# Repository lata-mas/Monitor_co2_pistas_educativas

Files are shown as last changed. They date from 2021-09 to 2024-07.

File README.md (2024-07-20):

# Monitor de CO2 con sensores NDIR intercambiables para evaluar la ventilación natural

En este repositorio se encuentran los archivos necesarios para replicar el monitor de CO2 desarrollado en el Instituto de Energías Renovables de la UNAM, ubicado en Temixco, Morelos, México.

Los archivos para el PCB se encuentran en el folder **electric_design**. Los archivos KiCAD del esquema del PCB y el diagrama eléctrico se encuentran en el folder **pcb_src**. Los archivos para maquinar o cortar por láser el PCB se encuentran en el folder **pcb_gerber**. El diagrama eléctrico en formato PDF se encuentra en el folder **pcb_pdf**. Las plantillas para producir el PCB por impresión de pantalla en formato JPG se encuentran en el folder **pcb_jpg**. Adicionalmente, renders tridimensionales del PCB con las partes del monitor se encuentran en el folder **pcb_view3D**. Los archivos para producir la carcasa del monitor de CO2 se encuentran en el folder **hardcase_pdf**. Los archivos FreeCAD se encuentran en el folder **cad**, junto con archivos en PDF para calcar en el folder **hardcase_pdf**, y también archivos en formato STL y DXF en el folder **hardcase_printable**.

El programa, código fuente y binario, se encuentran en el folder **software**. En el folder **notebook** se encuentran libretas de Jupyter con los datos de la calibración hecha y la campaña experimental, los datos se encuentran en el folder **dat**.

# Lista de componentes
| Designador  | Componente | Cantidad | Costo (MXN) | Fuente de materiales |
|---|---|---|---|---|
| ESP8266 | NodeMCU V3.0 Lolin | 1 | 159.0 | [Steren](https://www.steren.com.mx/placa-de-desarrollo-nodemcu-esp8266.html) |
| Sensor CO2  | S8LP | 1 | 800.0 | [Digikey](https://www.digikey.com.mx/es/products/detail/senseair/004-0-0053/10416532) |
| Sensor CO2  | SEN0220 | 1 | 1600.0 | [DFROBOT](https://www.dfrobot.com/index.php?route=product/product&product_id=1565) |
| Sensor CO2  | SCD30 | 1 | 1067.0 | [DigiKey](https://www.digikey.com.mx/es/products/detail/sensirion-ag/SCD30/8445334) |
| Pantalla | Pantalla de 4 dígitos | 1 | 112.0 | [Seeed Studio](https://www.seeedstudio.com/Grove-4-Digit-Display.html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) |
| LED | LED RGB | 1 | 4.3 | [Seeed Studio](https://www.seeedstudio.com/5mm-Triple-Output-LED-RGB-Common-cathode-20-PC-p-623.html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) |
| BUZZER | Zumbador activo | 1 | 27.7 | [Seeed Studio](https://www.seeedstudio.com/Grove-Buzzer.html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) |
| microUSB | Adaptador microUSB | 1 | 7.0 | [UElectronics](https://uelectronics.com/producto/adaptador-micro-usb-tipo-b-hembra-a-dip-pcb-5-pines/) |
| Botón | Botón pulsador | 1 | 27.7 | [Newark](https://www.newark.com/philmore/30-10062/product-range/dp/43W7727?st=button) |
| Batería | Banco de energía 2500 mAh | 1 | 200.0 | [Newark](https://www.newark.com/multicomp/mc011332/power-bank-5-2ah-5vdc/dp/94AC6834?st=power%20bank) |
| R1 | Resistencia de 10 kOhm | 1 | 2.5 | [Newark](https://www.newark.com/arcol/mra0207-10k-b-15ppm-ta/res-10k-0-10-250mw-axial/dp/79Y4556?st=resistor%2010kohm) |
| R2 | Resistencia de 220 Ohm | 3 | 2.5 | [Newark](https://www.newark.com/multicomp-pro/mccfr0w4j0221a50/carbon-film-resistor-220-ohm-250mw/dp/58K5029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) |
| Grove | Cable groove | 1 | 2.5 | [Seeed Studio](https://www.seeedstudio.com/Grove-Universal-4-Pin-Buckled-5cm-Cable-5-PCs-Pack.html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) |
| Terminal | Conector vertical de 4 pines GROVE 2mm | 1  | 2.5  | [Digikey](https://www.digikey.com.mx/en/products/detail/seeed-technology-co-ltd/110990030/5482560) |
| Pines | 40 pines hembra | 2 | 6.7 | [Seeed Studio](https://www.seeedstudio.com/2-54mm-pitch-pin-headers-Female-40pin-in-1-line-p-16.html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) |
| Tornillos | Tornillos M3 x 60 mm | 4 | 5.0 | [Amazon](https://www.amazon.com.mx/gp/product/B08XB8S55X/ref=ppx_yo_dt_b_search_asin_title?ie=UTF8&th=1) |
| Tuercas | Tuercas hexagonales M3-0.5 mm | 4 | 1.0 | [Amazon](https://www.amazon.com.mx/gp/product/B07ZFFFRJ5/ref=ppx_yo_dt_b_search_asin_title?ie=UTF8&th=1) |
| Popote | Popote rígido de plástico | 2 | 3.4 | [Amazon](https://www.amazon.com.mx/Pajitas-Repuesto-Pl%C3%A1stico-Reutilizables-Pinceles/dp/B0925H4F6R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) |
| Cable | Cable jumper o 22-26 AWG 6 cm | 2 | 1.8 | [Adafruit](https://www.adafruit.com/product/794) |

# Instrucciones de armado

El proceso de construcción se divide en cinco etapas. La primera etapa describe el ensamblaje del hardware para el monitor de CO2. La segunda etapa detalla la configuración y el procedimiento de carga del firmware para el ESP8266. En la tercera etapa se realiza una prueba de ensamblaje y en la cuarta etapa se lleva a cabo la configuración para la plataforma IoT. La quinta y última etapa implica el ensamblaje de la carcasa y la conexión de la batería USB si es necesario. Es importante destacar que el monitor de CO2 puede construirse y probarse en ausencia de los sensores de CO2, lo que permite adaptarse a posibles demoras en la entrega de componentes en regiones como México.

### Ensamblaje del monitor de CO2

Los siguientes pasos deben llevarse a cabo una vez que el usuario esté listo para construir el monitor de CO2, considerando que se puede probar y configurar aunque no haya un sensor de CO2 en el momento de la construcción, definiendo un sensor ficticio.

1. La PCB es de doble cara y puede producirse mediante serigrafía o mecanizado. Una de las caras tiene impresa la posición de las resistencias, sensores, led, etc., que se llamará cara frontal y el lado sin etiquetar cara trasera. Ambos lados de la PCB se muestran en la Figura 1a) cara frontal y 1b) cara trasera.
2. Soldar dos cables puente (6 cm de largo) al botón pulsador.
3. Soldar los siguientes componentes en la cara frontal. Cuatro resistencias, que están marcadas en la PCB como R1 para la resistencia de 10 $kOhm$ y R2, R3 y R4 son resistencias de 220 $Ohm$. Soldar dos líneas de quince pines hembra para el ESP8266. Soldar un conector hembra de cuatro pines para el LED. Para el botón, introducir los cables del botón en esta cara, por lo que la soldadura debería estar en la cara trasera. Insertar el conector vertical grove y soldar. En este punto, la PCB debería parecerse a la Figura 1c).
4. En la cara trasera, soldar lo siguiente: Soldar el adaptador MicroUSB y el conector hembra de tres pines para el zumbador, el conector hembra para este último debe estar doblado.
5. Si se usa S8LP, soldar dos líneas de conector hembra de seis pines en la cara trasera. En este punto, la cara trasera de la PCB debería parecerse a la Figura 1d). Luego soldar dos líneas de seis pines al sensor CO2 S8LP y enchufarlo en la PCB como se muestra en la Figura 2a).
6. Si se usa SCD30 o SEN0220, soldar una línea de conector hembra de cuatro pines en la cara trasera y, dependiendo del sensor, conectar como se muestra en la Figura 2b) para SCD30 y como se muestra en la Figura 2c) para SEN0220.
7. Enchufar el cable rojo del LED RGB apuntando al borde de la PCB en la cara frontal.
8. Enchufar la pantalla de 4 dígitos con un cable universal de cuatro pines con hebilla.
9. Enchufar el zumbador en el conector hembra de tres pines doblado.
10. Enchufar el ESP8266 con conexión microUSB alineada con el borde de la PCB.
<table>
  <tr>
    <td>
      <figure>
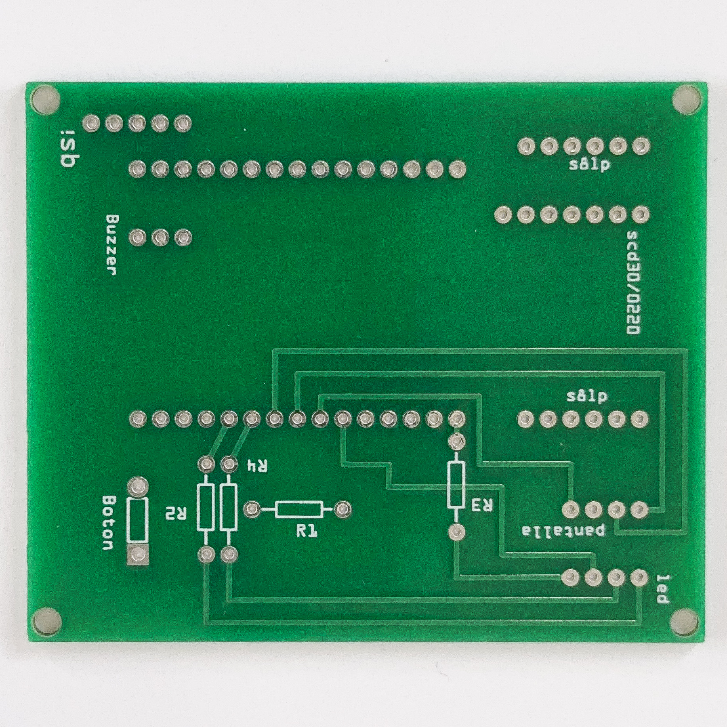
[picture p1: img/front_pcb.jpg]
Cara frontal de la PCB del monitor de CO2 sin componentes a) Cara frontal de la PCB sin componentes
        
        <figcaption>a)</figcaption>
      </figure>
    </td>
    <td>
      <figure>
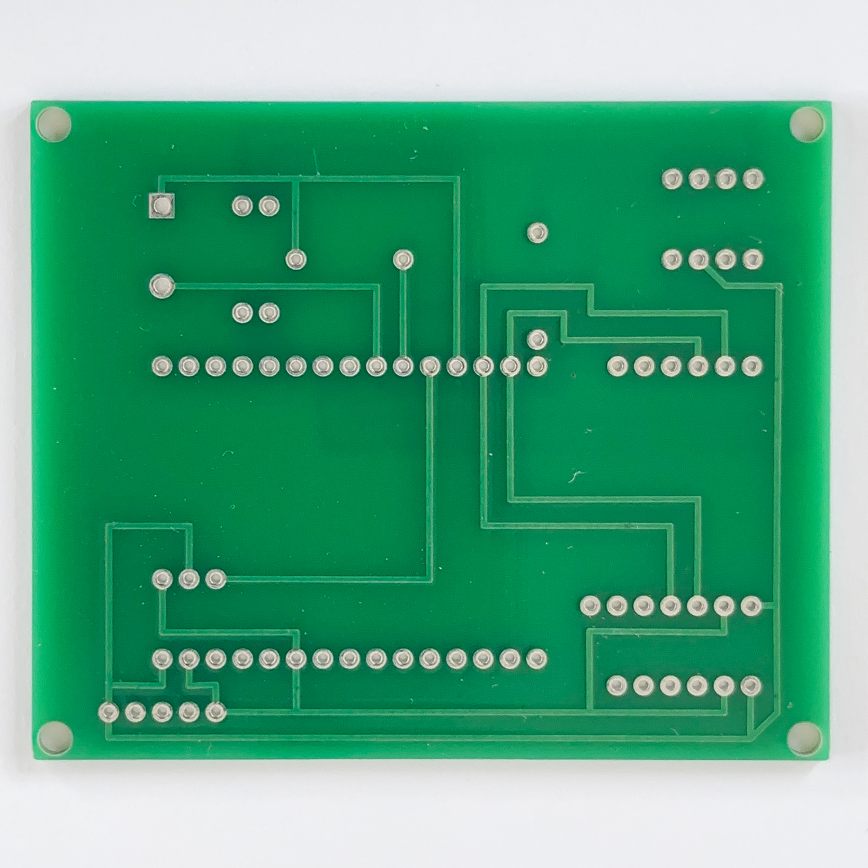
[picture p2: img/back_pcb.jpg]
Cara trasera de la PCB del monitor de CO2 sin componentes b) Cara trasera de la PCB sin componentes
        
        <figcaption>b) </figcaption>
      </figure>
    </td>
  </tr>
  <tr>
    <td>
      <figure>
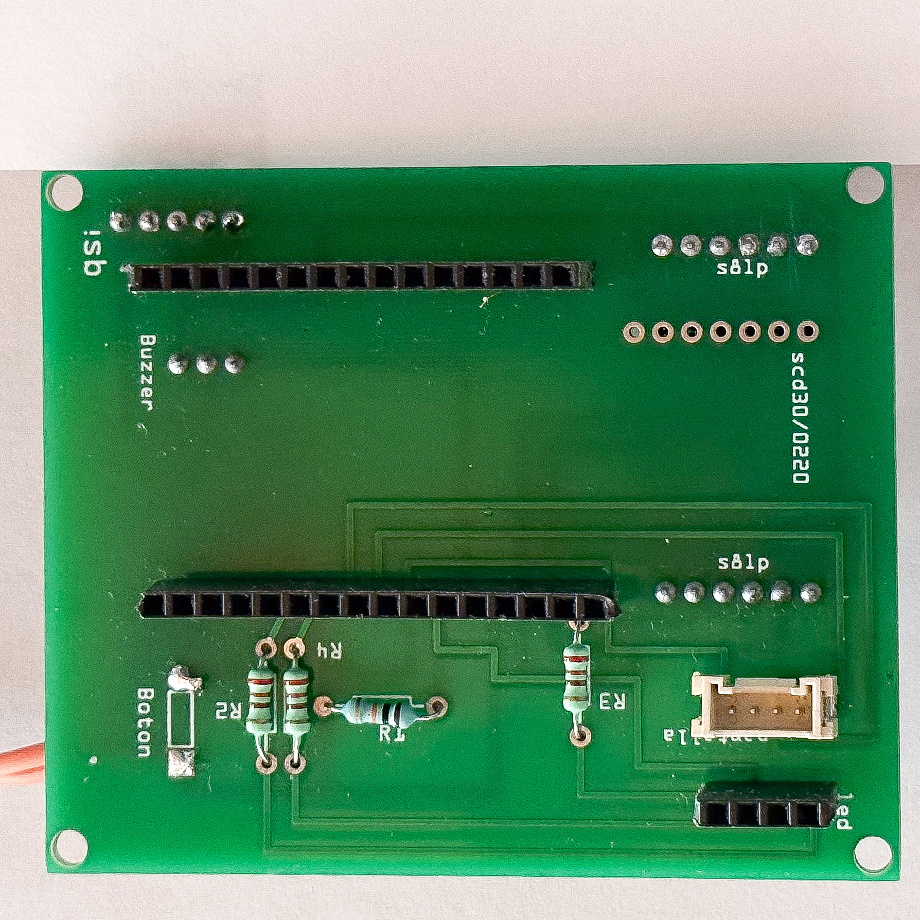
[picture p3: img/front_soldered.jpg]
Cara frontal de la PCB del monitor de CO2 con componentes soldados c) Cara frontal de la PCB con componentes soldados
        
        <figcaption>c) </figcaption>
      </figure>
    </td>
    <td>
      <figure>
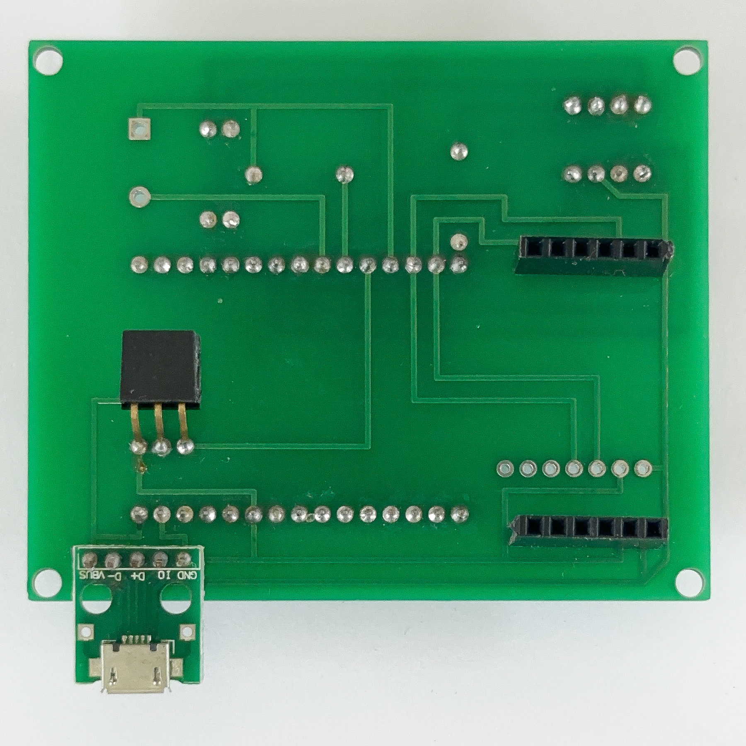
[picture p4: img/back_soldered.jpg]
Cara trasera de la PCB del monitor de CO2 con componentes soldados d) Cara trasera de la PCB con componentes soldados
        
        <figcaption>d) </figcaption>
      </figure>
    </td>
  </tr>
</table>

**Figura 1**: a) Cara frontal y b) cara trasera de la PCB para el monitor de CO2 sin componentes. Tras soldar los componentes c) cara frontal y d) cara trasera de la PCB. La cara frontal tiene etiquetas para los componentes.

<table>
  <tr>
    <td style="text-align: center;">
      <figure>
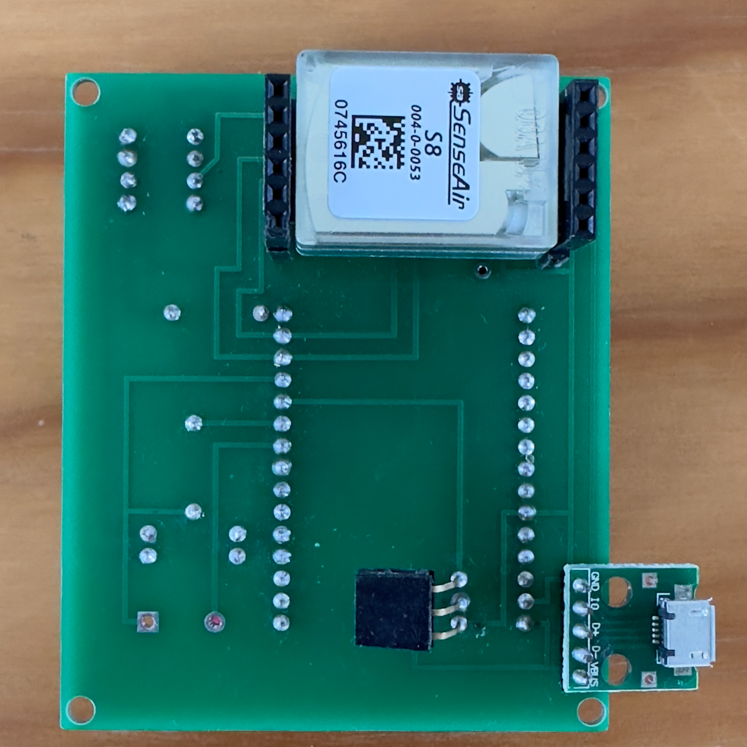
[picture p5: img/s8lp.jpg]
Sensor S8LP a) S8LP
        
        <figcaption>a) S8LP</figcaption>
      </figure>
    </td>
    <td style="text-align: center;">
      <figure>
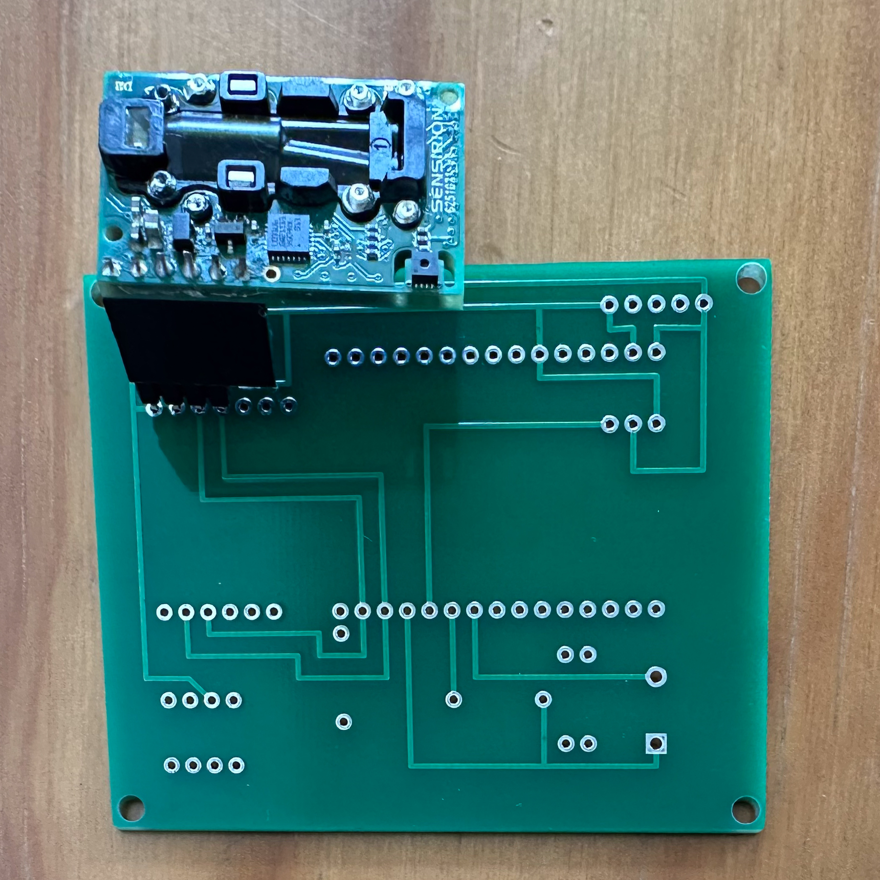
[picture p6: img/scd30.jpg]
Sensor SCD30 b) SCD30
        
        <figcaption>b) SCD30</figcaption>
      </figure>
    </td>
    <td style="text-align: center;">
      <figure>
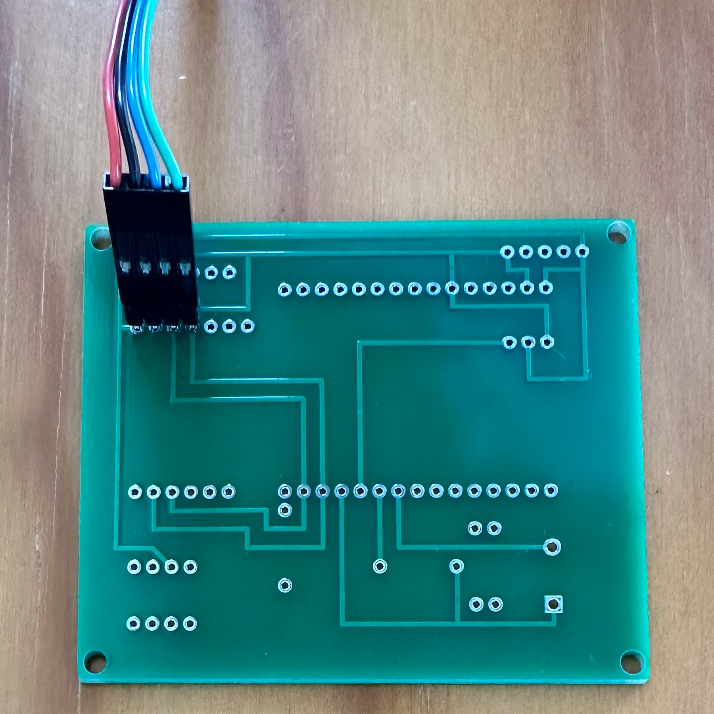
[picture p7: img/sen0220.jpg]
Sensor SEN0220 c) SEN0220
        
        <figcaption>c) SEN0220</figcaption>
      </figure>
    </td>
  </tr>
</table>

<figcaption>**Figura 2**: a) S8LP, b) SCD30, y c) SEN0220 sensores conectados en la cara trasera.</figcaption>

### Configuración y carga del firmware en el ESP8266

Antes de cargar el firmware en el ESP8266, en el archivo .ino, localiza la línea `#define S8LP` y reemplaza `S8LP` con el sensor de CO2 que hayas elegido. Las opciones disponibles son `DUMMY, SEN0220` y `SCD30`. Vale la pena mencionar que la opción `DUMMY` se utiliza cuando el sensor seleccionado no está disponible. Esta opción genera datos simulados, permitiendo evaluaciones preliminares del hardware.

Adicionalmente, en las líneas donde se define:

```
#define CO2_MIN 400
#define CO2_MID 600
#define CO2_MAX 700
```

tienes la opción de configurar los colores verde, amarillo y rojo, respectivamente, que también corresponden a la alarma audible.

En el archivo `arduino_secrets.h`, los usuarios deben especificar la URL de la plataforma IoT ThingsBoard. Además, el ESP8266 establece un servicio web específico para configurar la red WiFi a la que se unirá y el token del dispositivo donde el monitor de CO2 publicará sus datos. El nombre de usuario y contraseña del administrador pueden ajustarse en este archivo o mantenerse como están.

Una vez que todos los cambios necesarios estén hechos, el archivo .ino puede cargarse en el ESP8266 usando el Arduino IDE. Cuando se configura un gran conjunto de monitores de CO2, se recomienda exportar el archivo como un archivo binario. Para hacer esto, una vez abierto el archivo .ino y compilado para verificar errores, el usuario debe ir a Sketch, Export compiled binary y el archivo binario puede cargarse en diferentes monitores de CO2. En la carpeta /software/build del repositorio se puede encontrar el archivo binario que usamos para configurar los monitores de CO2 y un script bash, `foo.sh`, como referencia para cargar el binario usando esptool.

### Prueba de ensamblaje

Al encender el Monitor de CO2, este verificará si el zumbador y el LED RGB están funcionando correctamente. Si ambos funcionan bien, el zumbador emitirá un sonido y el LED RGB mostrará los colores rojo, verde y azul antes de comenzar a funcionar.

### Configuración para la plataforma IoT

Una vez cargado el firmware en el ESP8266 y encendido por primera vez, el monitor de CO2 establece automáticamente un punto de acceso denominado `monitorCO2-XXXXXXXXX` donde las `X` se reemplazan con los últimos nueve dígitos de la dirección MAC de cada ESP8266. Para configurar el token necesario y la información de WiFi, haz lo siguiente:

1. Conéctate a la red WiFi del monitor de CO2 llamada `monitorCO2-XXXXXXXXX` desde un computador cercano.
2. Abre un navegador y navega a `http://192.168.4.1`, donde te llevará a una interfaz de configuración.
3. Inicia sesión utilizando las credenciales predeterminadas: nombre de usuario `admin` y contraseña `password`. Estos corresponden a las constantes `SECRET_WWW_USERNAME` y `SECRET_WWW_PASSWORD` en el archivo .ino del firmware. A menos que el código haya sido modificado, estas serán las credenciales predeterminadas.
4. Luego se te solicitará que ingreses los detalles de la red WiFi que el ESP8266 utilizará para conectarse a Internet junto con su contraseña, también se te pedirá el token del dispositivo.
5. Después de proporcionar esta información, el monitor de CO2 almacenará los datos y desactivará su función de punto de acceso.
6. Reinicia el ESP8266.

Si decides no completar esta configuración, el monitor de CO2 seguirá siendo completamente operativo para mediciones pero no enviará datos a la plataforma IoT y el punto de acceso estará disponible hasta que se realice la configuración.

### Carcasa para el monitor de CO2 y batería

La carcasa del Monitor de CO2 consiste en dos láminas rígidas con recortes para la pantalla, el led y para el botón. Se ensambla con cuatro tornillos, tuercas y dos popotes cortados en ocho piezas (2.5 cm cada pieza) que se utilizan como separadores. Antes de ensamblar la carcasa, el monitor de CO2 debe parecerse a lo mostrado en la Figura 3 a) la cara frontal y b) la trasera usando el S8LP. En la Figura 4 a) se muestran las láminas rígidas para la carcasa con los recortes para el sonido, ranuras, pantalla, botón, led y tornillos para el ensamblaje. La pantalla se asegura a una de las láminas rígidas usando 2 tornillos que generalmente se incluyen con la pantalla. En la misma lámina, hay un orificio donde encaja el LED, en caso de usar tableros opacos. También tiene 4 orificios por los cuales pasarán los tornillos. Esta lámina corresponde a la cara frontal de la PCB. La otra lámina de la carcasa tiene un recorte para asegurar el botón y ranuras para asegurar una ventilación adecuada para el sensor de CO2.

Finalmente, el monitor de CO2 ensamblado con láminas transparentes como carcasa y con una batería USB adjunta se muestra en la Figura 4 b).

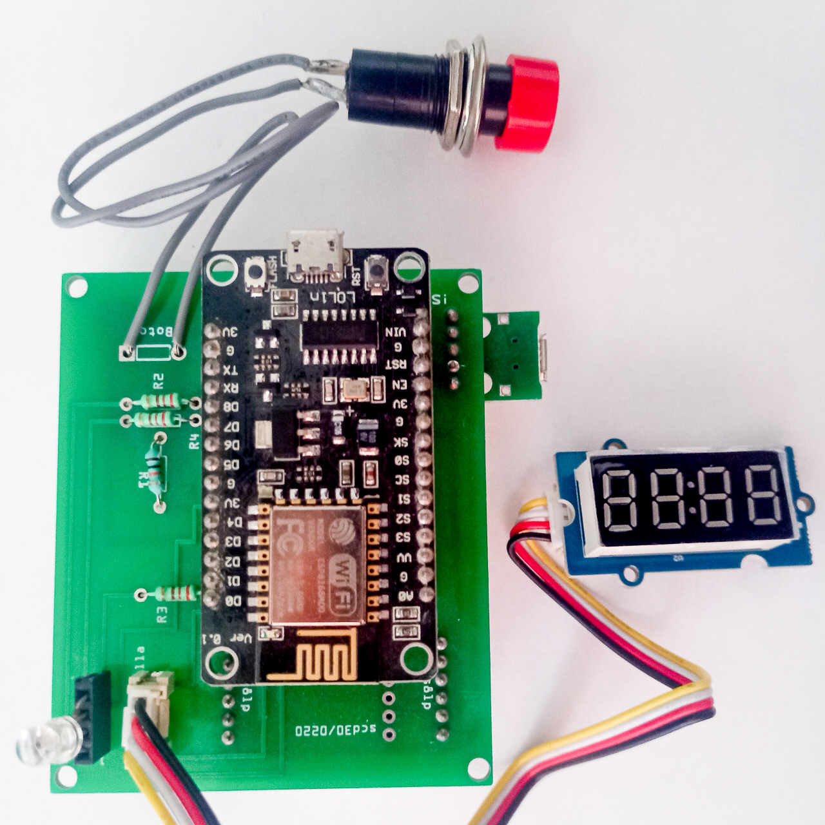
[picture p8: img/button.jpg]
Cara frontal de la PCB con todos los elementos soldados y enchufados

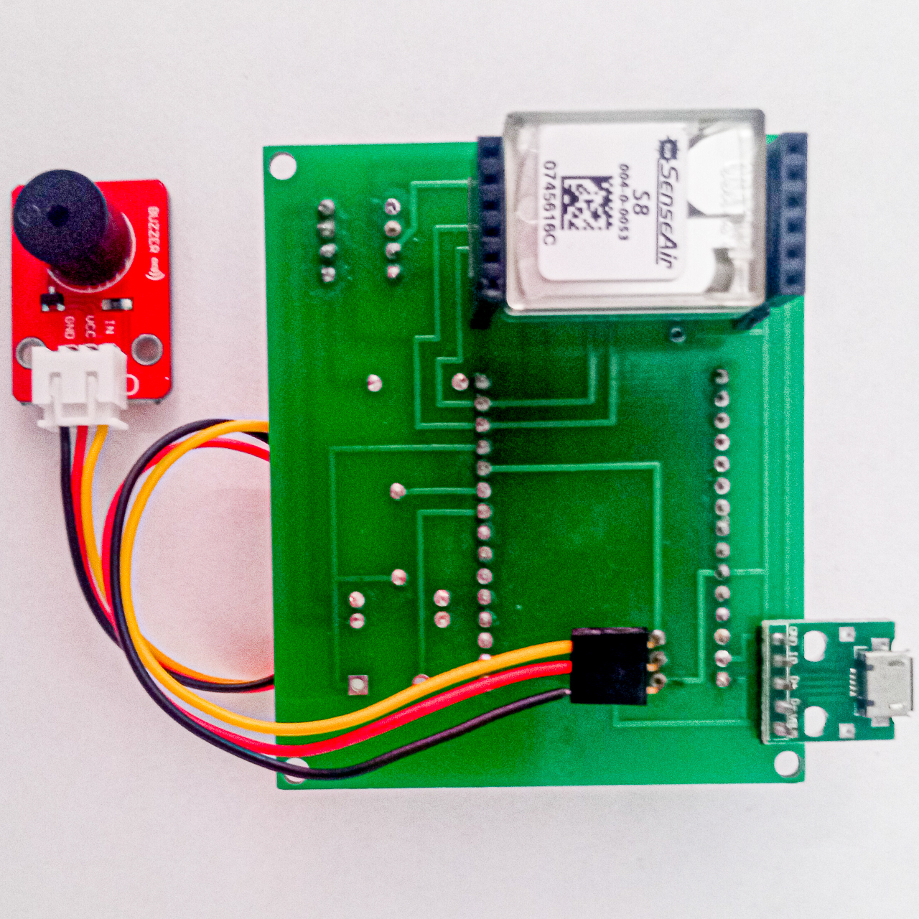
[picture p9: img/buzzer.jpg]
Cara trasera de la PCB con todos los elementos soldados y enchufados


**Figura 3**: a) Cara frontal y b) cara trasera de la PCB con todos los elementos soldados y enchufados.

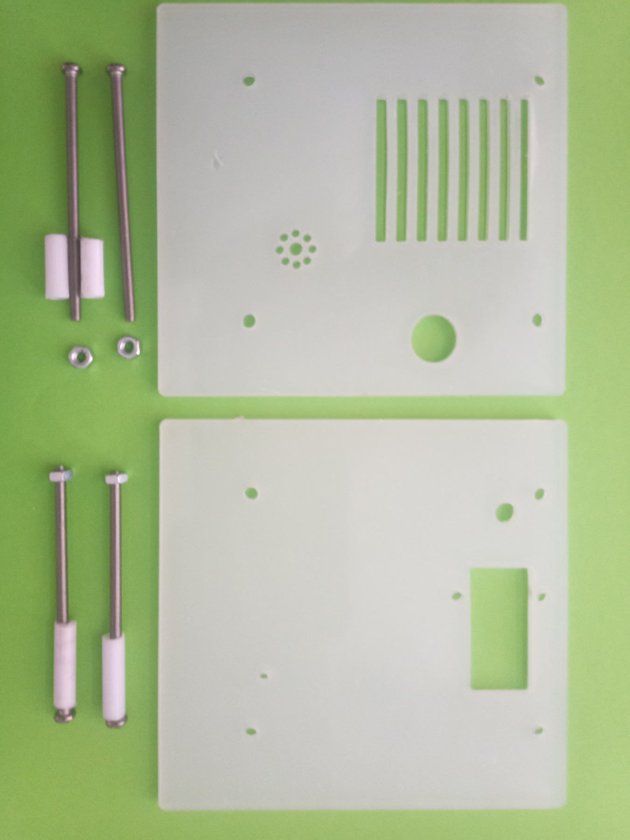
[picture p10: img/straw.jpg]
Láminas rígidas con recortes para la carcasa, tornillos y popotes rígidos

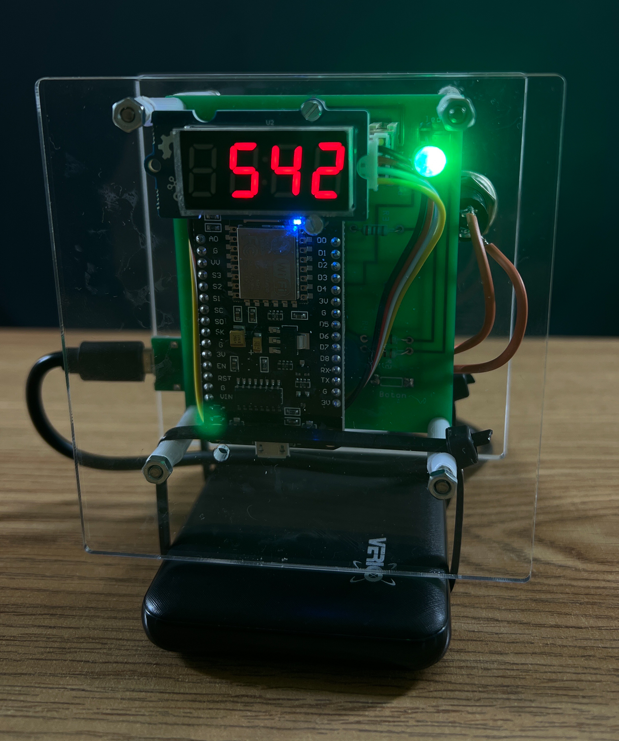
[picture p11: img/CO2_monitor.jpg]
Monitor de CO2 completamente ensamblado y funcionando, alimentado con una batería USB


**Figura 4**: a) Láminas rígidas con recortes para la carcasa, tornillos y popotes rígidos y b) Monitor de CO2 completamente ensamblado y funcionando, alimentado con una batería USB.

### Instrucciones de operación

Una vez que el monitor de CO2 está ensamblado y configurado, puede ser encendido utilizando el cable microUSB. Al activarse, el monitor comienza a medir las concentraciones de CO2, mostrando el promedio móvil de un minuto en su pantalla de 7 segmentos. Las alarmas visuales y sonoras preconfiguradas alertarán a los usuarios cuando sea necesario ventilar (indicado por una luz amarilla o dos pitidos) o si se recomienda evacuar el espacio (señalado por una luz roja y tres pitidos).

La alarma audible del Monitor de CO2 está diseñada para activarse cuando las concentraciones de CO2 alcanzan o superan las 600 ppm. Específicamente, para niveles entre 600 y 699 ppm, la alarma produce dos pulsos cada 20 segundos. Para concentraciones de 700 ppm o más, emite tres pulsos en el mismo intervalo. Esta característica auditiva es especialmente beneficiosa para usuarios con discapacidad visual que podrían tener dificultades con el sistema de colores o la lectura de la pantalla. Para desactivar temporalmente la alarma audible, presiona y mantén presionado el botón durante 20 segundos después del pitido. La alarma se reactivate una vez que las concentraciones de CO2 vuelvan al rango seguro de 400-599 ppm, asegurando alertas renovadas si los niveles exceden las 600 ppm. Si se prefiere, el zumbador puede ser excluido o desmontado del diseño sin afectar las funciones del monitor.

Los tres sensores seleccionados cuentan con un mecanismo de autocalibración que asume una exposición periódica al aire fresco (aproximadamente 400 ppm de CO2) durante la operación. Para una precisión de calibración óptima, los sensores deben experimentar exposición al aire fresco. Sin embargo, en entornos con concentraciones de CO2 consistentemente elevadas, la calibración manual puede ser más apropiada, ya que la falta prolongada de exposición a niveles ambientales puede resultar en desviaciones de calibración.

Si el Monitor de CO2 encuentra algún problema, mostrará uno de los siguientes códigos de error en su pantalla:
- F000: Imposible conectar al WiFi.
- E000: Falla en la medición del sensor de CO2.
- E001: Falla en la inicialización del sensor de CO2.
- E002: Falla en la modificación del intervalo de medición.
- E003: Falla en el comando de autocalibración.

Los mensajes de error E002 y E003 son exclusivos del sensor SCD30 y podrían aparecer durante su modo de autocalibración. Este modo puede ser activado dentro del código de Arduino a través de la función `InitSensor()`.

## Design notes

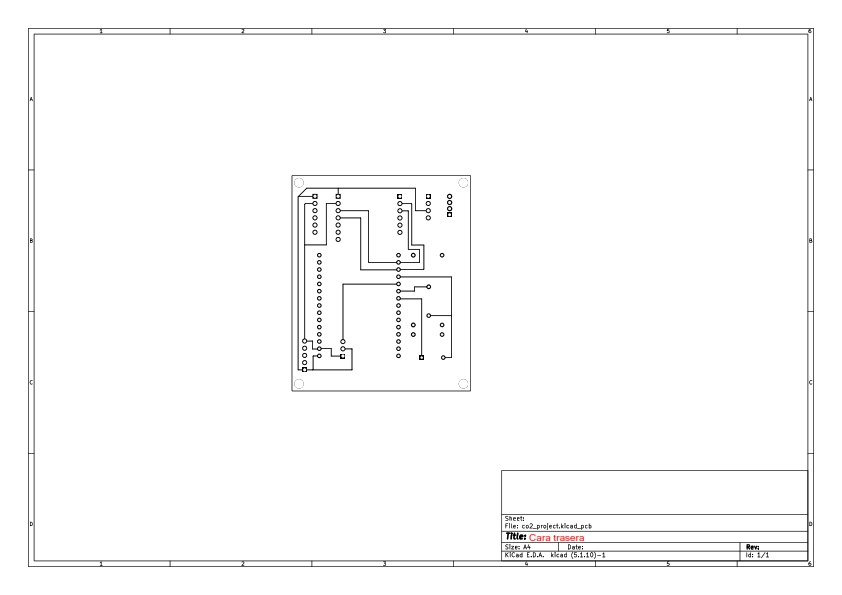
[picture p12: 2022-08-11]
electric_design/pcb_jpg/back_tracks.jpg

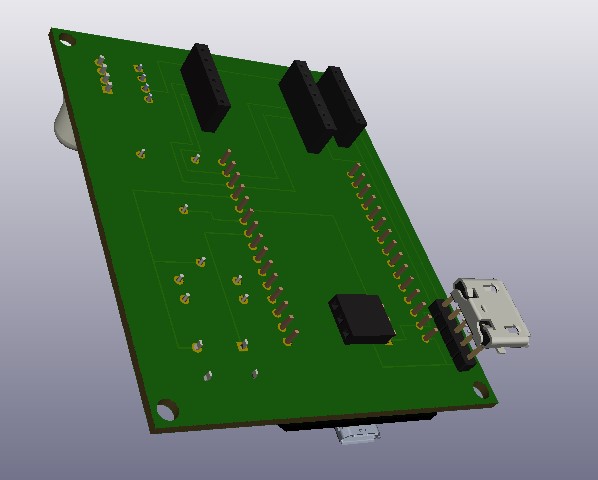
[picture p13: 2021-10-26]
electric_design/pcb_view3D/back_view.jpg

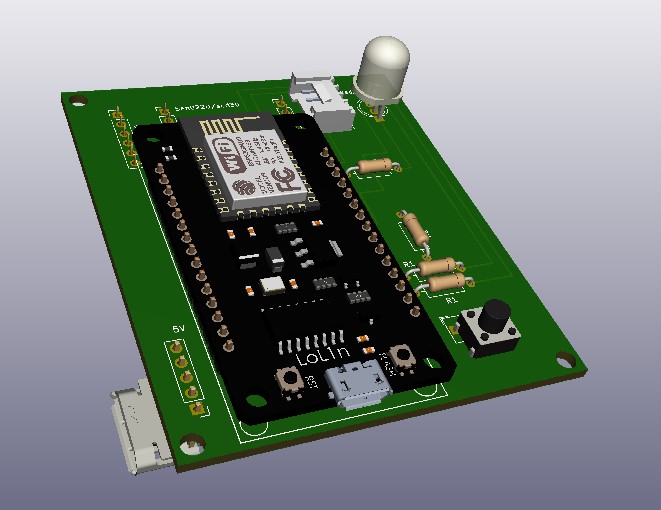
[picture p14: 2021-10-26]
electric_design/pcb_view3D/frontal_view.jpg

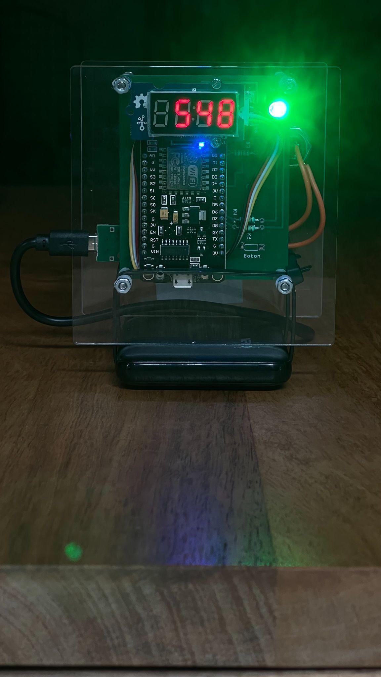
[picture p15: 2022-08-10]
img/monitorCO2.jpeg

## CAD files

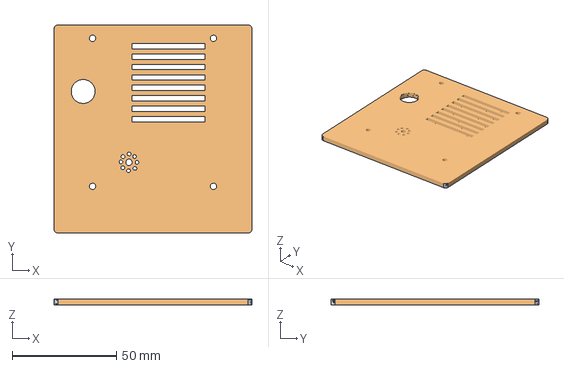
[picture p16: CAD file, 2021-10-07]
cad/back_face.FCStd
95.0 x 100.0 x 3.00 mm
Pad (Meshed)

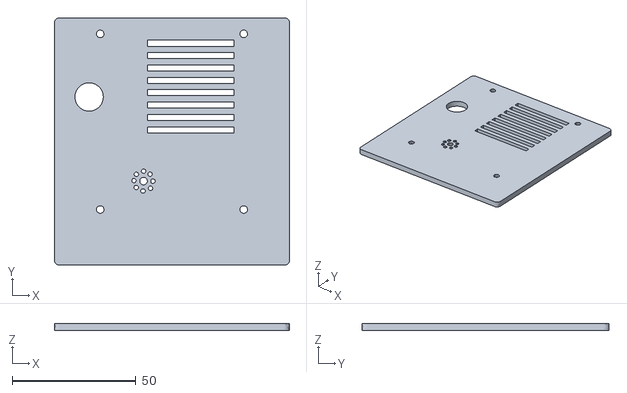
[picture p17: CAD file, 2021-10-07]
cad/hardcase_printable/back_face.stl
95.0 x 100.0 x 3.00

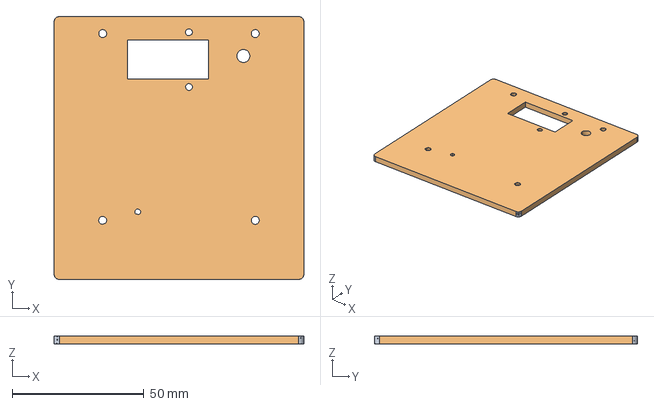
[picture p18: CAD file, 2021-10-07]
cad/front_face.FCStd
95.0 x 100.0 x 3.00 mm
Pad (Meshed)

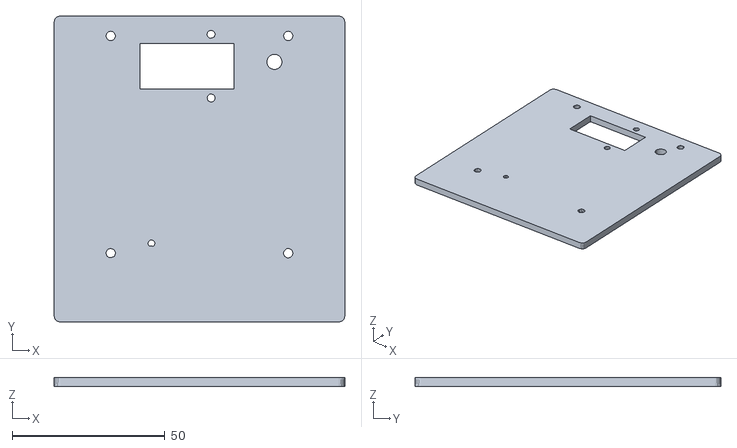
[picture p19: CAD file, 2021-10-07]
cad/hardcase_printable/front_face.stl
95.0 x 100.0 x 3.00

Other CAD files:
cad/hardcase_printable/back_face.dxf
cad/hardcase_printable/front_face.dxf

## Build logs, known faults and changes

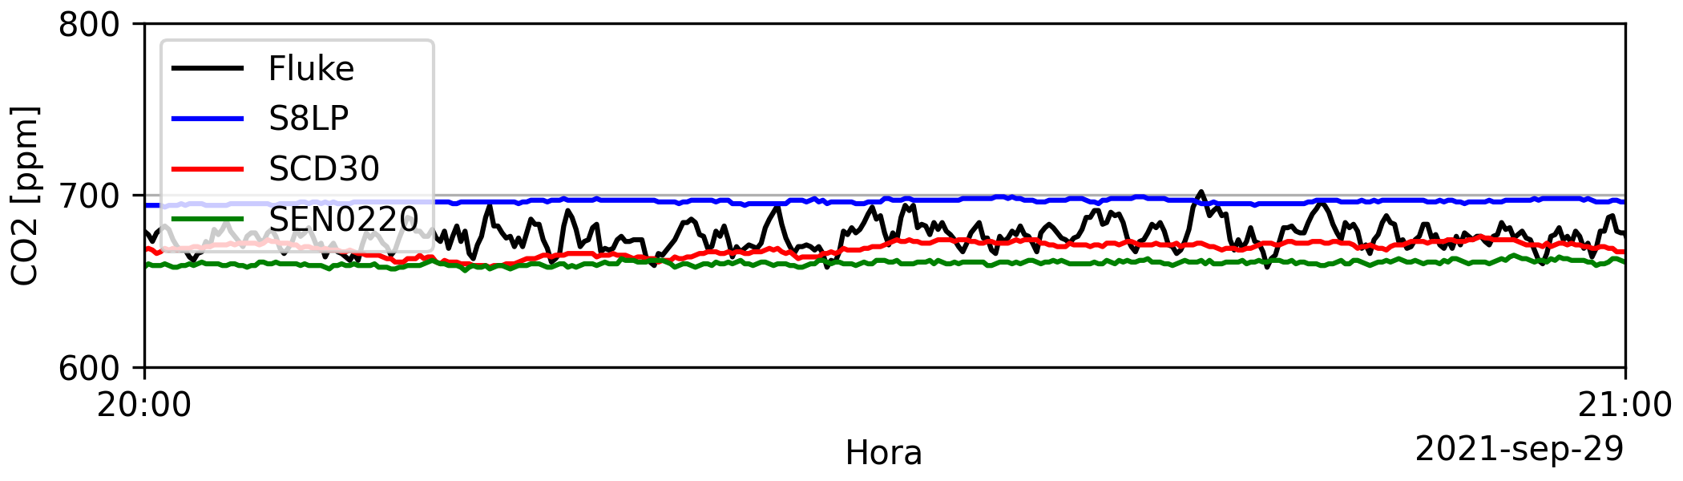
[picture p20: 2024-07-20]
img/history.png

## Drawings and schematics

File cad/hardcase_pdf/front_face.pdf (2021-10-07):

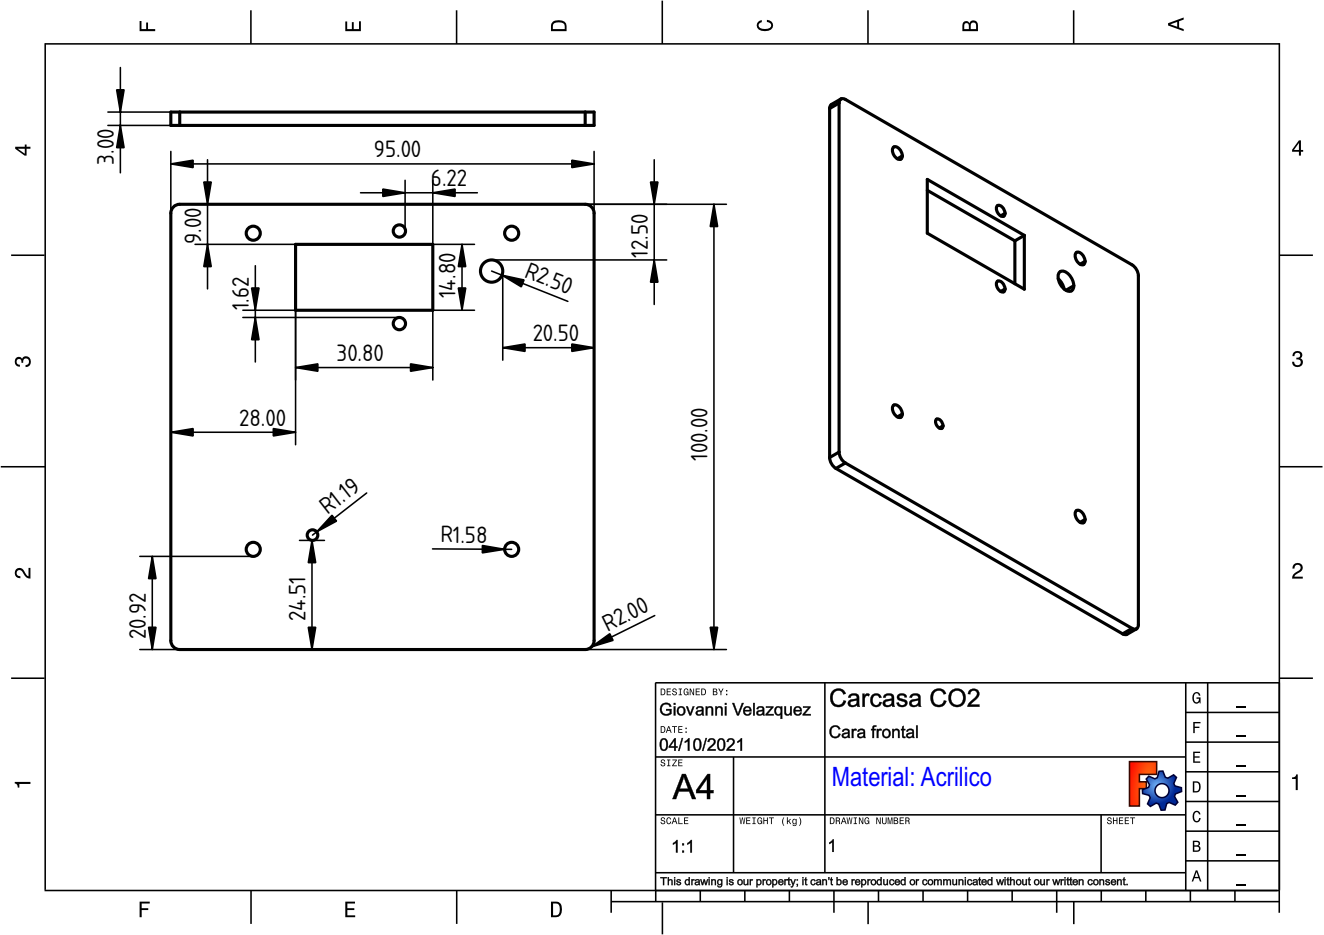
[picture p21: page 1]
Material: Acrilico

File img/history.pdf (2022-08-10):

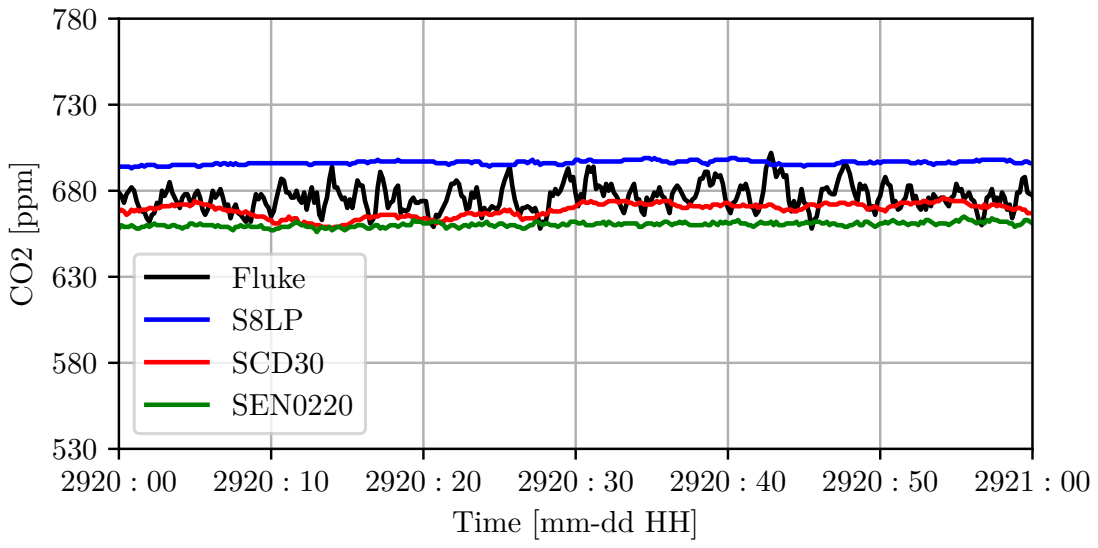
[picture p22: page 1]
CO2 [ppm]; Fluke; SCD30

SEN0220

Time [mm-dd HH]

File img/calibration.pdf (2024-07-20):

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

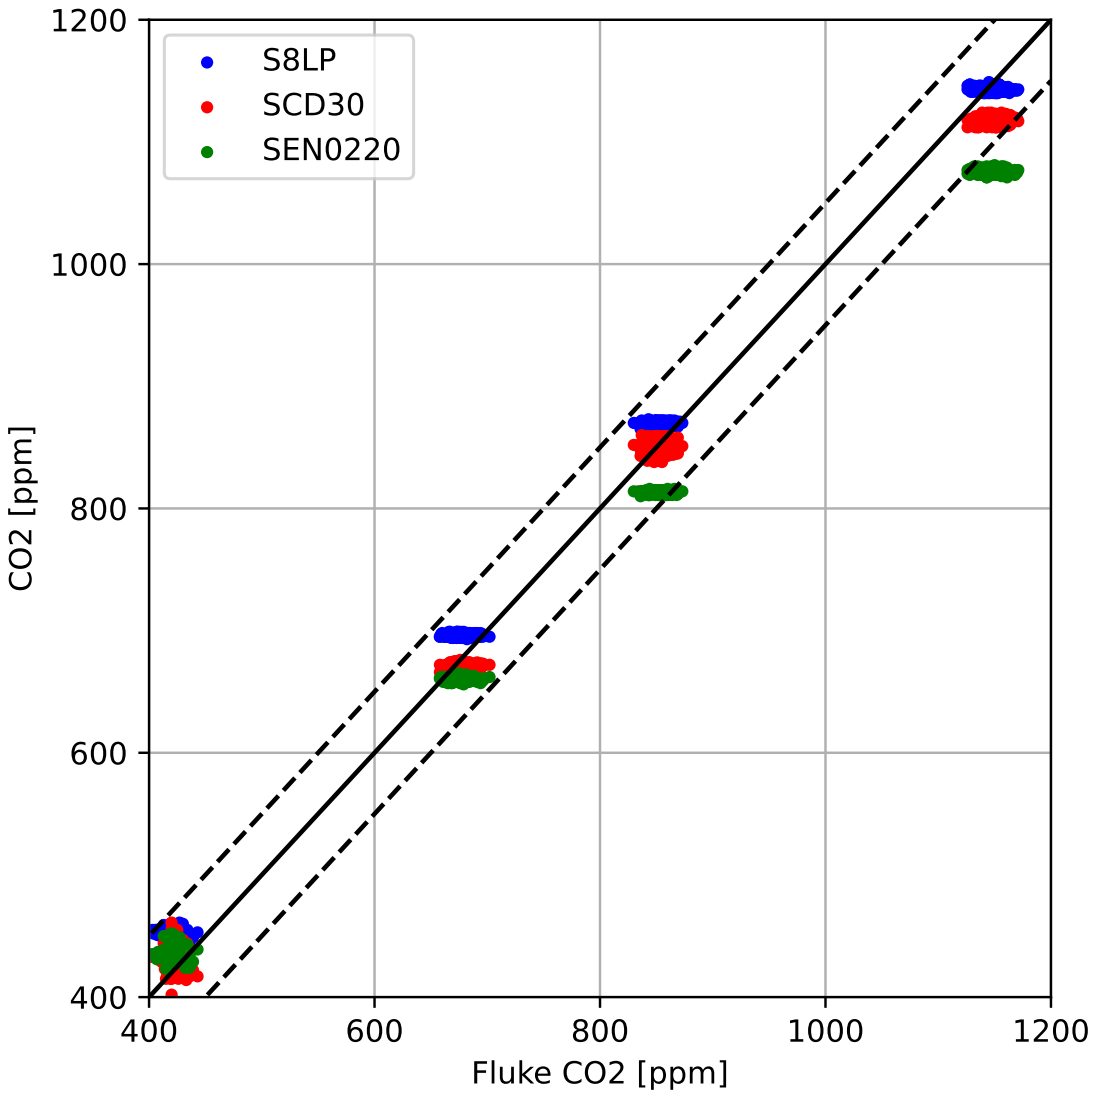
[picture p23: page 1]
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

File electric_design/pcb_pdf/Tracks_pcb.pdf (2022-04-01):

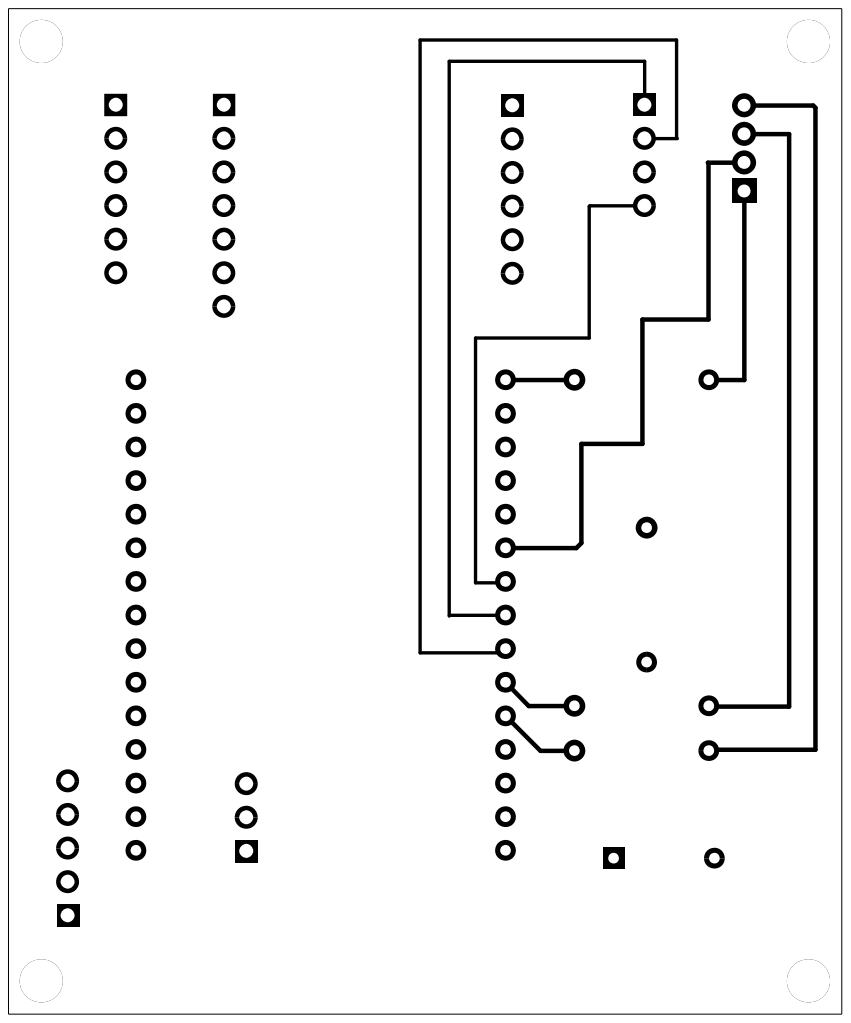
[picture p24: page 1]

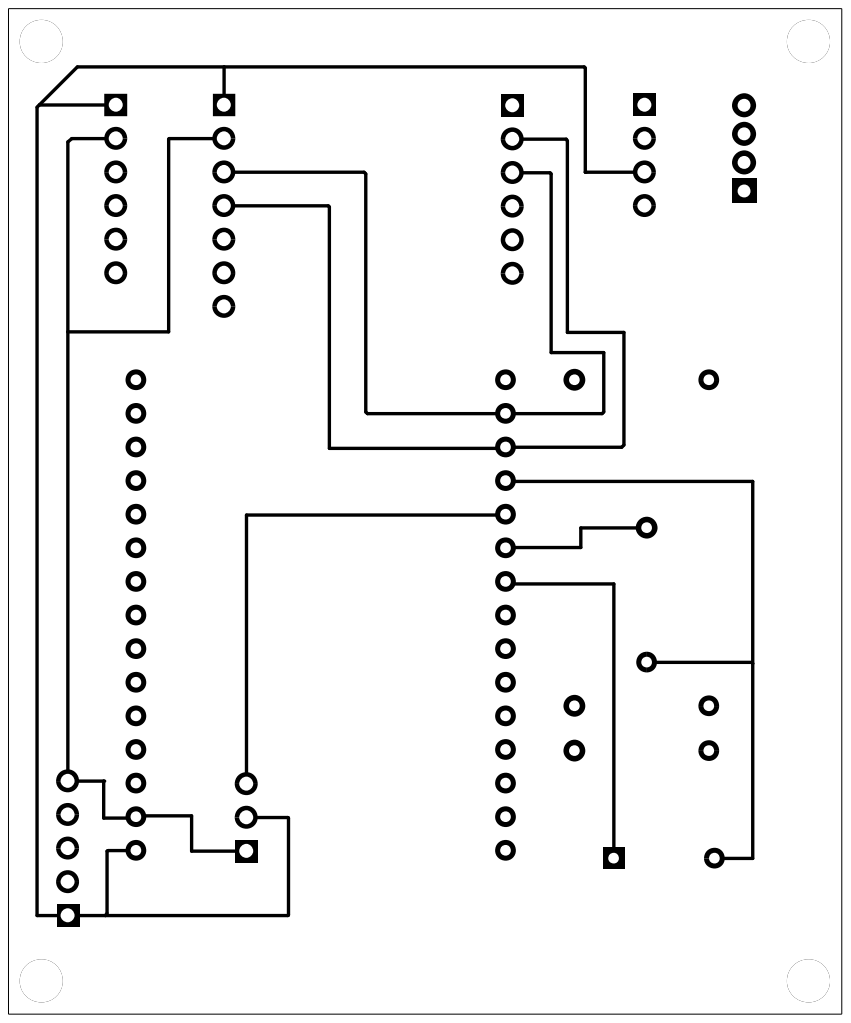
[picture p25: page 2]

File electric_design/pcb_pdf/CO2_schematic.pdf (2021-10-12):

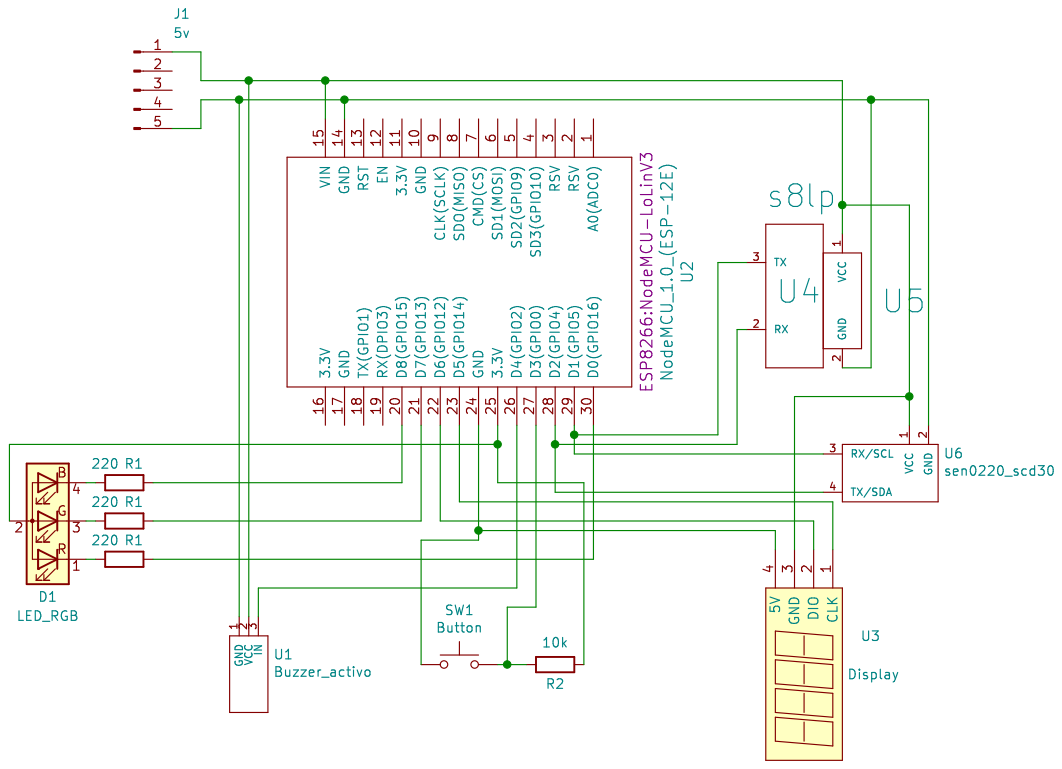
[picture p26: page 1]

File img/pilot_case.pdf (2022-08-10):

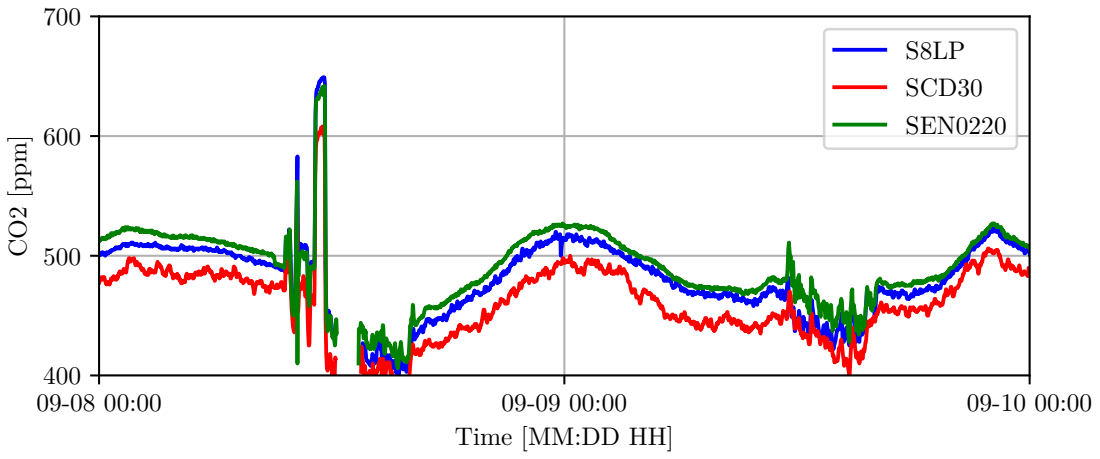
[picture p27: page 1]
CO2 [ppm]; S8LP SCD30 SEN0220

Time [MM:DD HH]

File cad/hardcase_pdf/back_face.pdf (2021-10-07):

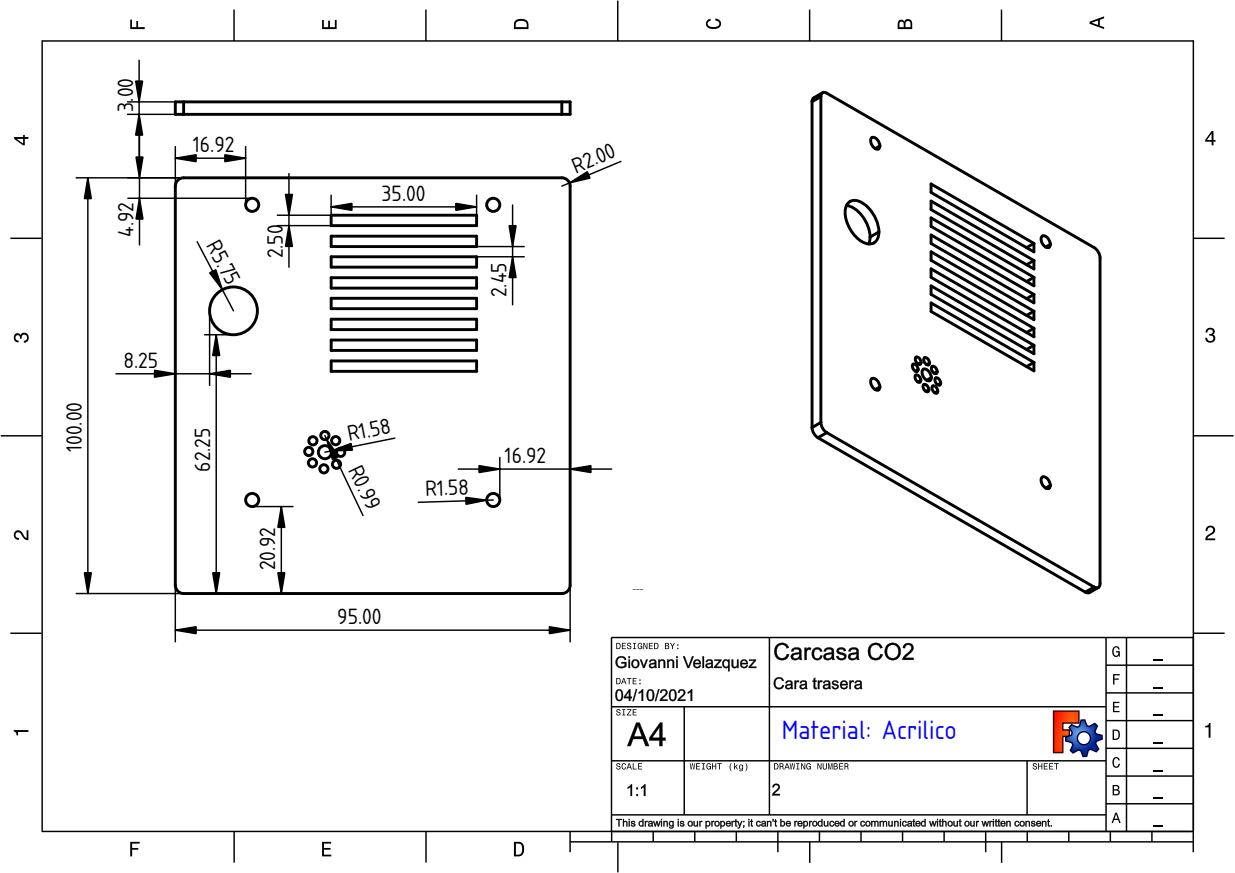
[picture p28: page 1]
aterial: Acrilico

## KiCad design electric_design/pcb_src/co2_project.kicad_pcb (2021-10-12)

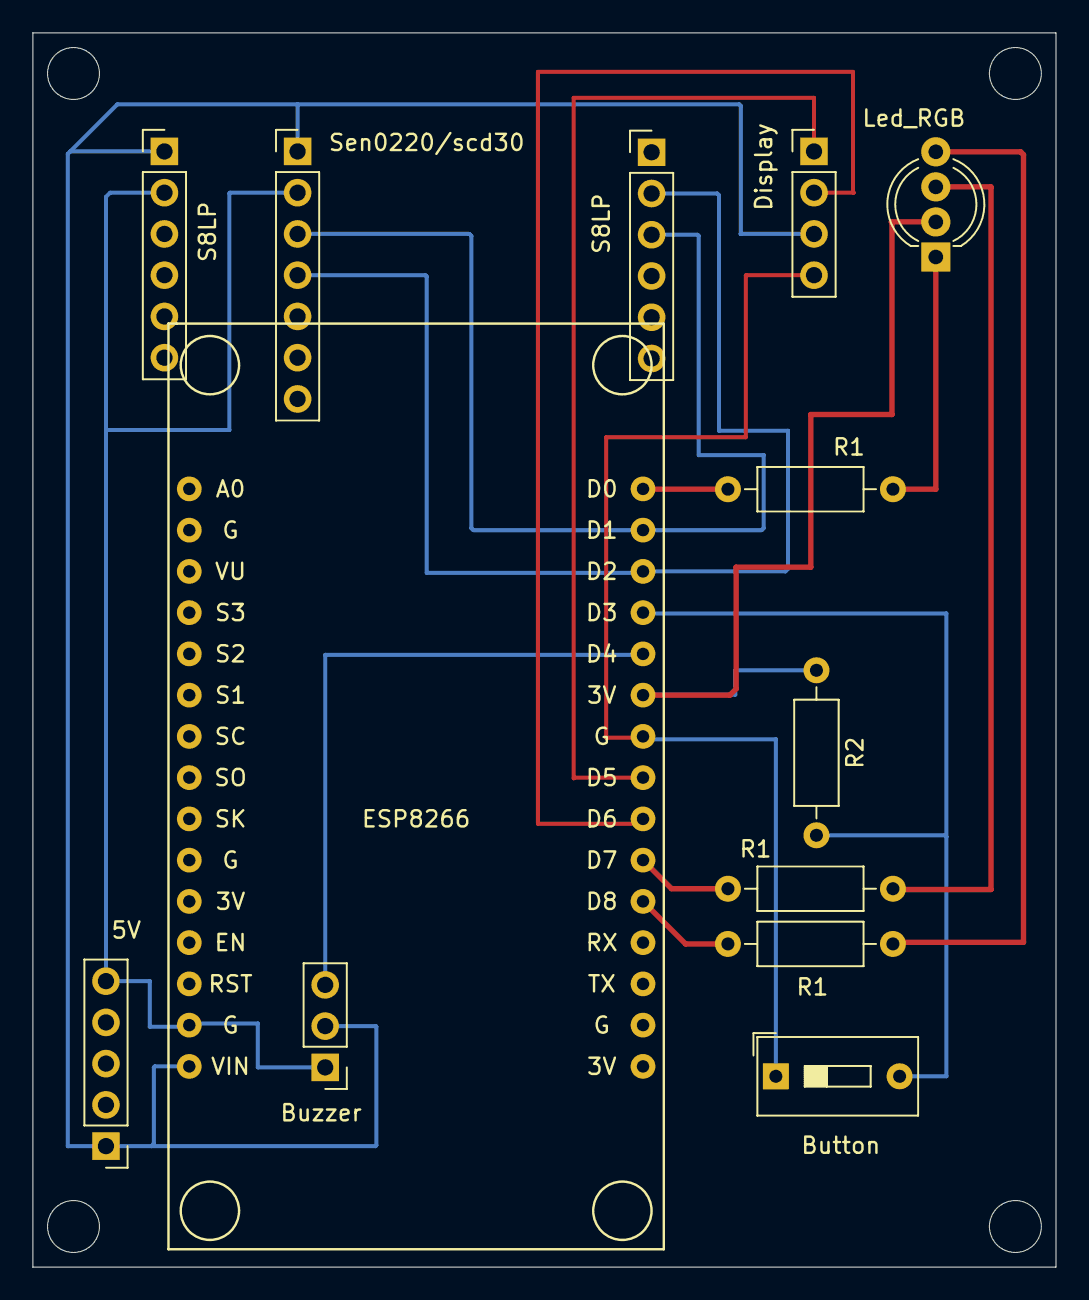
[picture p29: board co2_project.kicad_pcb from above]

Board: 2 copper layers, 63.0 x 76.0 mm, 13 parts (0 on the bottom side), 16 nets.

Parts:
5V: 5v; PinHeader_1x05_P2.54mm_Vertical
Button: Button; SW_DIP_SPSTx01_Slide_9.78x4.72mm_W7.62mm_P2.54mm
Buzzer: Buzzer_activo; PinHeader_1x03_P2.54mm_Vertical
Display: Display; PinHeader_1x04_P2.54mm_Vertical
ESP8266: NodeMCU_1.0_(ESP-12E); NodeMCU-LoLinV3
Led_RGB: LED_RGB; LED_D5.0mm-4_RGB_Wide_Pins
R1, R1#2, R1#3: 220; R_Axial_DIN0207_L6.3mm_D2.5mm_P10.16mm_Horizontal
R2: 10k; R_Axial_DIN0207_L6.3mm_D2.5mm_P10.16mm_Horizontal
S8LP: s8; PinHeader_1x06_P2.54mm_Vertical
S8LP#2: lp; PinHeader_1x06_P2.54mm_Vertical
Sen0220/scd30: sen0220_scd30; PinHeader_1x07_P2.54mm_Vertical

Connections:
unnamed: Led_RGB.1, R1#3.2
unnamed: ESP8266.25, Led_RGB.2, R2.1
unnamed: Led_RGB.3, R1#2.2
unnamed: Led_RGB.4, R1.2
unnamed: 5V.1, Buzzer.2, Display.3, ESP8266.15, S8LP#2.1, Sen0220/scd30.1
unnamed: 5V.5, Buzzer.1, ESP8266.14, S8LP#2.2, Sen0220/scd30.2
unnamed: ESP8266.20, R1.1
unnamed: ESP8266.21, R1#2.1
unnamed: ESP8266.30, R1#3.1
unnamed: Button.2, ESP8266.27, R2.2
unnamed: Button.1, Display.4, ESP8266.24
unnamed: Buzzer.3, ESP8266.26
unnamed: Display.2, ESP8266.22
unnamed: Display.1, ESP8266.23
unnamed: ESP8266.28, S8LP.2, Sen0220/scd30.4
unnamed: ESP8266.29, S8LP.3, Sen0220/scd30.3

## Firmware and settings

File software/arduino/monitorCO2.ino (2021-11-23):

#ifndef ARDUINO_ARCH_ESP8266
#error Requires NodeMCU esp8266 board
#endif 
#define DEBUG
/*
  monitorCO2.ino

  Optimized for NodeMCU ESP8266 dev board
    
  (C) 2021 Héctor Daniel Cortés González <hdcg@ier.unam.mx>
  (C) 2021 Instituto de Energías Renovables <www.ier.unam.mx>
  (C) 2021 Universidad Nacional Autónoma de México <www.unam.mx>

  Supported sensors:

  * DUMMY
    A dummy sensor for test purposes
    
  * SEN0220
    DFRobot SEN0220. UART interface.

  * S8LP
    SenseAir S8 Low Power. UART interface.

  * SCD30
    Sensirion SCD30 sensor module. i2c (TWI) interface
*/
#define S8LP

#include <ESP8266WiFi.h>
#include <ESP8266HTTPClient.h>
#include <ESP8266mDNS.h>
#include <ESP8266WebServer.h>
#include <Ticker.h>
#include <TM1637Display.h>
#include "myEEPROM.h"
#include "arduino_secrets.h"
#include "cma.h"

#define MAX_READ_ERRORS 8
#define MAX_WIFI_ERRORS 8

#define CLK 14
#define DIO 12

#define POST_INTERVAL 60
#define POST_MINIMAL
#define ALARM_INTERVAL 20

#define LED_RED 16
#define LED_GREEN 15
#define LED_BLUE 13

#define CO2_MIN 400
#define CO2_MID 600
#define CO2_MAX 700

#define BUZZER 2

#define BUTTON_0  0

#define DELAY 1024
#define SHORT_DELAY 128
#define LONG_DELAY 8192

const byte ledRGB[]={LED_RED, LED_GREEN, LED_BLUE};
const byte colorBlack[]={1,1,1}; // 1=OFF 0=ON
const byte colorGreen[]={1,0,1};
const byte colorYellow[]={0,0,1};
const byte colorRed[]={0,1,1};

/*
const char* ssid = SECRET_SSID;
const char* pass = SECRET_PASS;
*/

WiFiMode_t wifiMode;

myEEPROM myEEPROM;
eeprom_data_t *eeprom_data;

Ticker tickerSensor;
Ticker tickerPost;
Ticker tickerBuzzer;

TM1637Display display(CLK, DIO);

#define ERROR_WIFI_NOT_CONNECTED 0xf000
#define ERROR_SENSOR_READ 0xe000
#define ERROR_SENSOR_INIT 0xe001
#define ERROR_MEASUREMENT_INTERVAL 0xe002
#define ERROR_ASC_FAILED 0xe003

/*
 * Esta parte está incompleta
 */
#define LISTEN_PORT 80

ESP8266WebServer server(LISTEN_PORT);

/*
 * Fin de la parte incompleta
 */

#ifdef SCD30
/****************************************
 * Sensor SCD30 0-10K CO2 ppm            
 *   i2c addr = 0x61
 *   Thanks Lady Ada!
 ****************************************/
#include <Adafruit_SCD30.h>
#define MEASUREMENT_INTERVAL 2

Adafruit_SCD30 scd30;

short initSensor() {
  if(!scd30.begin()) {
#ifdef DEBUG
    Serial.println(F("Init scd30 failed!"));
#endif
    noReturn(ERROR_SENSOR_INIT);
  }
  delay(SHORT_DELAY);
  
  if(scd30.getMeasurementInterval()!=MEASUREMENT_INTERVAL) {
#ifdef DEBUG
    Serial.printf(PSTR("Interval=%d\n"), MEASUREMENT_INTERVAL);
#endif
    delay(SHORT_DELAY);
    if(!scd30.setMeasurementInterval(MEASUREMENT_INTERVAL)) noReturn(ERROR_MEASUREMENT_INTERVAL);
  }

  if(!scd30.selfCalibrationEnabled()) {
    delay(SHORT_DELAY);
    if(!scd30. selfCalibrationEnabled(true)) noReturn(ERROR_ASC_FAILED);
#ifdef DEBUG
    Serial.println(F("ASC enabled..."));
#endif
  }
  return 0;
}

short readSensor() {
  if (!scd30.dataReady()) return -1;
  if (!scd30.read()) return -1;
  return scd30.CO2;
}

#define SENSOR_NAME "scd30"
#endif

#if defined(SEN0220) || defined(MH_Z14A)
/****************************************
 * Sensor SEN0220 0-50K CO2 ppm            
 *   Serial1 requires Arduino Leonardo
 *   or similar board
 *   (CC) 2021 <hdcg@ier.unam.mx>
 ****************************************/
#include <SoftwareSerial.h>
#define RX_SW 5
#define TX_SW 4
#define MEASUREMENT_INTERVAL 2

SoftwareSerial SerialSW(RX_SW, TX_SW);

unsigned char hexdata[] = {0xFF,0x01,0x86,0x00,0x00,0x00,0x00,0x00,0x79}; 

typedef struct {
  byte ff, cmd, hi, lo, fill[4], crc;
} data_sen0220_t;

short sen0220(void) {
  union {
    struct { byte lo, hi; };
    word w;
  } retval;
  data_sen0220_t data;
  SerialSW.write(hexdata,sizeof(hexdata));
  SerialSW.listen();
  delay(500); // TO BIG!
  if (SerialSW.available()>0) { 
    SerialSW.readBytes((char*)&data, 9);
    if((data.ff != 0xff) && (data.cmd != 0x86)) return -1;
    retval.hi=data.hi;
    retval.lo=data.lo;
    return retval.w;
  }
  else return -1;    
}

unsigned char SET_RANGE_2K[] = {0xFF,0x01,0x99,0x00,0x00,0x00,0x07,0xD0,0x8F};

short initSensor() {
  SerialSW.begin(9600);
  delay(SHORT_DELAY);
  SerialSW.write(SET_RANGE_2K, sizeof(SET_RANGE_2K));
  delay(SHORT_DELAY);
  if(sen0220()==-1) return -1;
  else return 0;
}

short readSensor() {
  return sen0220();
}

#ifdef SEN0220
#define SENSOR_NAME "sen0220"
#elif defined(MH_Z14A)
#define SENSOR_NAME "mh-z14a"
#endif
#endif

#ifdef S8LP
/****************************************
 * SenseAir S8            
 *   UART interface
 *   (CC) 2021 <hdcg@ier.unam.mx>
 ****************************************/
#include <SoftwareSerial.h>
#define RX_SW 5
#define TX_SW 4
#define MEASUREMENT_INTERVAL 4

SoftwareSerial SerialS8(RX_SW, TX_SW);

static const byte S8_CMD_STATUS[]  = {0xfe, 0x04, 0x00, 0x00, 0x00, 0x01, 0x25, 0xc5};
static const byte S8_CMD_CO2READ[] = {0xfe, 0x04, 0x00, 0x03, 0x00, 0x01, 0xd5, 0xc5};

typedef struct {
  byte addr,
   function_code,
   count,
   hi,
   lo,
   crc_hi,
   crc_lo;
} s8data_t;

typedef union {
    struct {
      byte lo,hi;
    };
    word w;
  } retval_t;

#define S8_WAIT_DELAY 100

short s8status(void) {
  retval_t retval;
  s8data_t data;
  
  SerialS8.write((char*)S8_CMD_STATUS, sizeof(S8_CMD_STATUS));
  SerialS8.listen();
  delay(S8_WAIT_DELAY);
  if (SerialS8.available()>0)
    SerialS8.readBytes((char*)&data,sizeof(data));
  else return -1;
  
  if((data.addr != 0xfe) && (data.function_code != 0x04)) return -1;
  else {
    retval.hi=data.hi;
    retval.lo=data.lo;
    return retval.w;
  }
}

short s8co2read(void) {
  retval_t retval;
  s8data_t data;
  
  SerialS8.write((char*)S8_CMD_CO2READ, sizeof(S8_CMD_CO2READ));
  SerialS8.listen();
  delay(S8_WAIT_DELAY);
  if (SerialS8.available()>0)
    SerialS8.readBytes((char*)&data,sizeof(data));
  else return -1;

  if((data.addr != 0xfe) && (data.function_code != 0x04)) return -1;
  else {
    retval.hi=data.hi;
    retval.lo=data.lo;
    return retval.w;
  }
}

short initSensor() {
  SerialS8.begin(9600);
  delay(SHORT_DELAY);
  return s8status();
}

short readSensor() {
  return s8co2read();
}

#define SENSOR_NAME "s8lp"
#endif 

#ifdef DUMMY
/****************************************
 * Dummy Sensor
 *   (CC) 2021 <hdcg@ier.unam.mx>
 ****************************************/
#define MEASUREMENT_INTERVAL 5

static int myDummyData=450;

short initSensor() {
  static boolean st = true;
  if(st) {
    randomSeed(0xc0cac07a);
    st = false;
  } else random();
  if (millis()&1!=0) return 0;
  else return -1;
}

short readSensor() {
  switch(random(10)) {
    case 1: return -1; // read error
    case 2: return ++myDummyData;
    case 3: return --myDummyData;
    case 5: return myDummyData+=10;
    case 8: return myDummyData-=10;
    default: return myDummyData;
  }
}

#define SENSOR_NAME "dummy"
#endif

#ifndef SENSOR_NAME
#error "PLEASE SELECT A SENSOR"
#endif
/*********************
 * Main program here!
 *********************/

void displayError(unsigned short errorCode) {
  boolean led=false;      
  for(short d=0; d<DELAY; d+=SHORT_DELAY) {
    if(led=!led) display.showNumberHexEx(errorCode,0,true);
    else display.clear();
    delay(SHORT_DELAY);
  }
}

void noReturn(unsigned short errorCode) {
  for(boolean led=false;;delay(SHORT_DELAY)) {
    if(led=!led) display.showNumberHexEx(errorCode, 0, true);
    else display.clear();
  }
}

#ifdef _CMA_H_
#define SAMPLES (POST_INTERVAL/MEASUREMENT_INTERVAL)

CMA cmaCO2(SAMPLES);
#endif

void setup() {
  pinMode(BUTTON_0, INPUT);
  pinMode(CLK, OUTPUT);
  pinMode(DIO, OUTPUT);
  pinMode(LED_RED, OUTPUT);
  pinMode(LED_GREEN, OUTPUT);
  pinMode(LED_BLUE, OUTPUT);
  pinMode(BUZZER, OUTPUT);

#ifdef DEBUG
  Serial.begin(115200);
  delay(SHORT_DELAY);
#endif

#ifdef DEBUG
  Serial.println();
  Serial.println(F("*****************************"));
  Serial.println(F(" Proyecto monitorCO2"));
  Serial.println(F(__DATE__  " " __TIME__));
  Serial.println(F("(C) 2021, <hdcg@ier.unam.mx>"));
  Serial.println(F("(C) 2021, LaTA+"));
  Serial.println(F("(C) 2021, IER-UNAM"));
  Serial.println(F("(C) 2021, UNAM"));
  Serial.println(F("*****************************"));
  Serial.println();

  Serial.println(F("Sensor: " SENSOR_NAME));
#endif

  powerOnSelfTest();

#ifdef DEBUG
  Serial.println(F("Init..."));
#endif
  while(1) {
    short st=initSensor();
    if(st==0) break;
    displayError(ERROR_SENSOR_INIT);
  }

  String mDNSname = WiFi.macAddress().substring(9);
  mDNSname.toLowerCase();
  mDNSname.replace(":","");
  mDNSname = F("monitorCO2-") + mDNSname;
/*
 * Check EEPROM data
 */
  eeprom_data = new eeprom_data_t;

  if(myEEPROM.readData(eeprom_data)) {
#ifdef DEBUG
    Serial.println(F("OK EEPROM DATA, WIFI-STATION..."));
#endif
    WiFi.mode(wifiMode=WIFI_STA);
    WiFi.begin(eeprom_data->wifi_ssid, eeprom_data->wifi_pass);
    chkwifi(true);
  } else {
#ifdef DEBUG
    Serial.println(F("NO EEPROM DATA, WIFI-ACCESS-POINT..."));
#endif
    WiFi.mode(wifiMode=WIFI_AP);
    WiFi.softAP(mDNSname);
  }

#ifdef DEBUG
  Serial.print(F("mDNS:"));
  Serial.println(mDNSname);
#endif
  MDNS.begin(mDNSname);

#ifdef DEBUG
  Serial.println(F("Ticker..."));
#endif
  tickerSensor.attach(MEASUREMENT_INTERVAL, tckrRead);
  tickerPost.attach(POST_INTERVAL, tckrPost);
  tickerBuzzer.attach_ms(SHORT_DELAY, tckrBuzzer);

  /*
   * Esta sección está incompleta
   */
#ifdef DEBUG
  Serial.println(F("WebServer..."));
#endif
/*
 * WEB SERVER SETUP
 */
  server.on(F("/"), handleRoot);
  server.on(F("/commit"), HTTP_POST, handleCommit);
  server.on(F("/reset"), handleReset);
#ifdef SCD30
  server.on(F("/FRC"), handleFRC);
  server.on(F("/ASC"), handleASC);
#endif
  server.begin();
#ifdef DEBUG
  Serial.println("HTTP server started...");
#endif
  /*
   * Termina la sección incompleta
   */
#ifdef DEBUG
  Serial.println("leaving setup()");
#endif
}

volatile short co2ppm = -1;
volatile boolean isTime2read = true;
volatile boolean isTime2post = true;
volatile boolean isTime2buzz = false;
volatile boolean isMuted = false;

void loop(void) {
  if(isTime2buzz) { // FIRST FASTER
    doBuzzer();
    isTime2buzz=false;
  }
  if(isTime2read) { 
    doReadSensor();
    isTime2read=false;
  }
  if(isTime2post) { // LAST SLOWER
    doPost();
    isTime2post=false;
  }
  server.handleClient();
}

void tckrPost() { isTime2post = true; }
void tckrRead() { isTime2read = true; }

/*
 * doReadSensor
 * 
 * keep rgbLED state
 * trigger ALARM 
 */

volatile char alarmCounter=0;

void doReadSensor(void) {
  short x = readSensor();
#ifndef _CMA_H_
  co2ppm = x;
#endif
  static byte readErrors=0;
  if(x<=0) { // CHECK READ ERRORS
    readErrors++;
#ifdef DEBUG
    Serial.print("readSensor Error: ");
    Serial.println(readErrors);
#endif
    displayError(ERROR_SENSOR_READ);
    if(readErrors>MAX_READ_ERRORS) ESP.reset();
    return; 
  } else if(readErrors>0) readErrors--;
    
#ifdef _CMA_H_
  cmaCO2.addData(x);
  co2ppm = cmaCO2.avg();
#endif

#ifdef DEBUG
  Serial.print(F("CO2ppm="));
  Serial.println(co2ppm);
#endif
  display.showNumberDec(co2ppm);

  const byte *color=colorBlack;
  if(co2ppm>=CO2_MIN && co2ppm<CO2_MID) {
#ifdef DEBUG
    Serial.println("GREEN");
#endif
    color=colorGreen;
    if(isMuted) isMuted=false;
    if(alarmCounter>0) alarmCounter=0;
  }
  else if(co2ppm>=CO2_MID && co2ppm<CO2_MAX) {
#ifdef DEBUG
    Serial.println("YELLOW");
#endif
    color=colorYellow;
    if(alarmCounter>0) alarmCounter--;
    else startAlarm(4); // 4 STATE CHANGES, 2 BEEPS, 1/2 SECOND
  }
  else if(co2ppm>=CO2_MAX) {
#ifdef DEBUG
    Serial.println("RED");
#endif
    color=colorRed;
    if(alarmCounter>0) alarmCounter--;
    else startAlarm(6); // 6 STATE CHANGES, 3 BEEPS, 3/4 SECOND
  }
  for(byte i=0; i<3; ++i)
    digitalWrite(ledRGB[i], color[i]);
}

/*
 * BUZZER over TICKER
 */

volatile byte buzzerDuration = 0;

void startAlarm(byte duration) {
  if(duration==0) return;
  buzzerDuration=duration;
  alarmCounter=(ALARM_INTERVAL/MEASUREMENT_INTERVAL);
}

void tckrBuzzer(void) {
  if(buzzerDuration>0) {
    buzzerDuration--;
    isTime2buzz=true;
  }
}

void doBuzzer() {
  if(isMuted) {
#ifdef DEBUG
    Serial.println("Buzzer is MUTED");
#endif
    return;
  }
  boolean state=(buzzerDuration&1)!=0; // ENABLE ON HIGH
#ifdef DEBUG
  Serial.printf(PSTR("Buzzer %s\n"), 
    state?PSTR("ON"):PSTR("OFF"));
#endif
  digitalWrite(BUZZER, state);
  if(!state && digitalRead(BUTTON_0)==LOW) isMuted=true;
}

/*
 * POST/KEEP WiFi
 */

void doPost(void) {
  if(wifiMode==WIFI_AP) return;
  static byte wifiErrors=0;
  if(!WiFi.isConnected()) {
    if(++wifiErrors>MAX_WIFI_ERRORS) ESP.reset();
    WiFi.reconnect();
    chkwifi(false);
  } else if(wifiErrors>0) wifiErrors--;

  MDNS.update();
  
  WiFiClient wifiClient;
  HTTPClient httpClient;

  String payload = F("{");
  payload += F("\"" SENSOR_NAME "\":");
  payload += String(co2ppm);
#ifndef POST_MINIMAL
  payload += F(",\"heartbeat\":");
  payload += millis();
#ifdef SCD30
  payload += F(",\"temperature\":");
  payload += String(scd30.temperature, 1);
  payload += F(",\"relative_humidity\":");
  payload += String(scd30.relative_humidity, 0);
#endif
#endif
  payload += F("}");

  String URL=F(SECRET_URL_PREFIX) + eeprom_data->access_token + F(SECRET_URL_POSTFIX);
  
#ifdef DEBUG
  Serial.println(WiFi.localIP());
  Serial.print(F("POST: "));
  Serial.println(payload);
  Serial.println(URL);
#endif

  httpClient.begin(wifiClient, URL);
  httpClient.addHeader(F("Content-Type"), F("application/json"));

  int statusCode = httpClient.POST(payload);
  
#ifdef DEBUG
  Serial.print(F("ST="));
  Serial.print(statusCode);
  if(statusCode<0) {
    Serial.print(":");
    Serial.print(httpClient.errorToString(statusCode));
  }
  Serial.println();
#endif
}

void chkwifi(boolean retry) {
  int st;

  delay(SHORT_DELAY);
#ifdef DEBUG
  Serial.print(F("WiFi SSID: "));
  Serial.println(WiFi.SSID());
#endif

  while(!WiFi.isConnected()) {
#ifdef DEBUG
    st = WiFi.status();
    Serial.print("WiFi.status=");
    Serial.println(wl_status_to_string(st));
#endif
    displayError(ERROR_WIFI_NOT_CONNECTED+st);
    if(!retry) break;
    static byte i=1;
    if((i<<=1)==0) break;
  }
#ifdef DEBUG
  if(WiFi.isConnected()) {
    Serial.print("IP address=");
    Serial.println(WiFi.localIP());
  }
#endif
}

const char* wl_status_to_string(int status) {
  switch (status) {
    case WL_NO_SHIELD: return "WL_NO_SHIELD";
    case WL_IDLE_STATUS: return "WL_IDLE_STATUS";
    case WL_NO_SSID_AVAIL: return "WL_NO_SSID_AVAIL";
    case WL_SCAN_COMPLETED: return "WL_SCAN_COMPLETED";
    case WL_CONNECTED: return "WL_CONNECTED";
    case WL_CONNECT_FAILED: return "WL_CONNECT_FAILED";
    case WL_CONNECTION_LOST: return "WL_CONNECTION_LOST";
    case WL_DISCONNECTED: return "WL_DISCONNECTED";
  }
  return NULL;
}

void powerOnSelfTest(void) {
  short holdButton=0;
#ifdef DEBUG
  Serial.println("Power On Self Test...");
#endif  
  while(1) {
#ifdef DEBUG
    Serial.println("DISPLAY=8888");
#endif
    display.setBrightness(0x07);
    display.showNumberDec(8888);

    for(byte led=0; led<3; led++) {
#ifdef DEBUG
      switch(led) {
        case 0: Serial.println("LED RED"); break;
        case 1: Serial.println("LED GREEN"); break;
        case 2: Serial.println("LED BLUE"); break;
      }
#endif
      digitalWrite(BUZZER, HIGH);
      digitalWrite(ledRGB[led], LOW);
      delay(SHORT_DELAY);
      digitalWrite(BUZZER, LOW);
      delay(SHORT_DELAY);
      digitalWrite(ledRGB[led], HIGH);
    }
    display.clear();
    delay(SHORT_DELAY);
    if(digitalRead(BUTTON_0)==HIGH) break;
    holdButton++;
#ifdef DEBUG
    Serial.println(holdButton);
#endif
  }
  if(holdButton>3) {
#ifdef DEBUG
    Serial.println(F("Erasing EEPROM...")); 
#endif
    myEEPROM.clear();
  }
}
/*
 * WEBSERVER
 * 
 * Esta parte está incompleta
 * 
 */
 
void handleRoot() {
#ifdef DEBUG
  Serial.println(F("handleRoot()"));
#endif
  server.send(200, F("text/html"), F("<!DOCTYPE html>"
"<html><body>"
"<h1>MonitorCO2</h1>"
"<p>Proporciona los siguientes datos:</p>"
"<form action=\"/commit\" method=\"post\">"
"<label for=\"ssid\">WiFi SSID:</label><br>"
"<input type=\"text\" id=\"ssid\" name=\"ssid\"><br>"
"<label for=\"pass\">WiFi password:</label><br>"
"<input type=\"text\" id=\"pass\" name=\"pass\"><br>"
"<label for=\"token\">Access Token:</label><br>"
"<input type=\"text\" id=\"token\" name=\"token\"><br>"
"<input type=\"submit\" value=\"Submit\">"
"</form>"
"</body></html>")
  );
}

void handleCommit() {
#ifdef DEBUG
  Serial.println(F("handleCommit()"));
#endif
  for (uint8_t i = 0; i < server.args(); i++) {
    if(server.argName(i)=="token") 
      eeprom_data->access_token=server.arg(i);
    if(server.argName(i)=="ssid") 
      eeprom_data->wifi_ssid=server.arg(i);
    if(server.argName(i)=="pass") 
      eeprom_data->wifi_pass=server.arg(i);
  }
  myEEPROM.writeData(eeprom_data);
  server.send(200, "text/html", "<!DOCTYPE html>"
"<html><body>"
"<h1>MonitorCO2</h1>"
"<p>Datos grabados, por favor, reinicia el monitorCO2</p>"
"</body></html>"
  );
}

const char* www_username = SECRET_WWW_USERNAME;
const char* www_password = SECRET_WWW_PASSWORD;

void handleReset() {
#ifdef DEBUG
  Serial.println(F("handleReset()"));
#endif
  if (!server.authenticate(www_username, www_password))
    return server.requestAuthentication();
  myEEPROM.clear();
  server.send(200, "text/plain", "Reset OK");
}

#ifdef SCD30
void handleFRC(void) {
  if (!server.authenticate(www_username, www_password))
    return server.requestAuthentication();
  scd30.forceRecalibrationWithReference(450);  // perhaps this is a parameter?
  server.send(200, "text/plain", "FRC started");
}

void handleASC(void) {
  if (!server.authenticate(www_username, www_password))
    return server.requestAuthentication();
  scd30.selfCalibrationEnabled(true);
  server.send(200, "text/plain", "ASC started");
}
#endif

/*
 * Termina la parte incompleta
 */
 

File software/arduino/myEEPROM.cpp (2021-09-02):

#include "myEEPROM.h"

myEEPROM::myEEPROM() { EEPROM.begin(512); }
myEEPROM::~myEEPROM() { EEPROM.end(); }

char myEEPROM::readChar() {
  char ch;
  ch=EEPROM.read(address++);
  crc.add(ch);
  return ch;
}

char myEEPROM::writeChar(const char ch) {
  crc.add(ch);
  EEPROM.write(address++, ch);
  return ch;
}

char myEEPROM::readCRC() {
  return EEPROM.read(511);
}

char myEEPROM::writeCRC() {
  char ch = crc.getCRC();
  EEPROM.write(511, ch);
  return ch;
}

String myEEPROM::readString() {
  String retval;
  byte len=readChar();
  for(byte i=0; i<len; i++)
    retval += readChar();
  return retval;
}

String myEEPROM::writeString(const String S) {
  byte len=S.length();
  writeChar(len);
  for(byte i=0; i<len; i++)
    writeChar(S.charAt(i));
  return S;
}

boolean myEEPROM::readData(eeprom_data_t *p) {
// RESET
  crc.reset(); 
  address=0;
// MAGIC NUMBER
  if(readChar()!='X') return false;
  if(readChar()!='G') return false;
// REV number
  if(readChar()!=REV) return false;
// AQUI COMIENZA LO BUENO
  p->access_token = readString();
  p->wifi_ssid = readString();
  p->wifi_pass = readString();
// READ CRC
  if(EEPROM.read(511)!=crc.getCRC()) return false;
  return true;
}

boolean myEEPROM::writeData(eeprom_data_t *p) {
// RESET
  crc.reset();
  address=0;
// Write MAGIC number
  writeChar('X');
  writeChar('G');
// Write REV number
  writeChar(REV);
// AQUI EMPIEZA LO BUENO
  writeString(p->access_token);
  writeString(p->wifi_ssid);
  writeString(p->wifi_pass);
// WRITE CRC
  writeCRC();
// COMMIT  
  return EEPROM.commit();
}

boolean myEEPROM::clear(const char ch) {
  for(address=0; address<512; address++)
    EEPROM.write(address, ch);
  return EEPROM.commit();
}

void myEEPROM::dump() {
  char ch;
  for(address=0; address<512; address++) {
    if((address&0x0f)==0) Serial.printf("%04x ", address);
    ch=EEPROM.read(address);
    if(ch<16) Serial.print("0");
    Serial.print(ch, HEX);
    if((address&0x0f)==0x0f) Serial.println();
  }
}

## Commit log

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2021-06-10 inclui datos del fluke
    [fluke.csv]
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2021-06-22 libreta actualizada para cargar todos los datos a un df
    [referencia.csv, sensores.csv]
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2021-06-25 correcion de horario y seleccion de fechas
    [sensores_20210624_20210625.csv]
2021-06-25 libreta de prueba nocturna del Turbo
    [aranet4_20210624.csv, sensores_20210623_20210625.csv, sensores_20210624_20210625.csv]
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2021-06-29 agregue prueba de camara hermetica
    [aranet4_2021-06-28T12_08_22.csv, fluke_25062021_28062021.csv, referencia2.csv]
2021-06-30 agregue datos de sensores thingsboard
    [fluke_28-06-2021_29-06-2021.csv, sensores_30-06-2021.csv]
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2021-06-30 agregue nuevamente datos de sensores thingsboard
    [sensores_30-06-2021_02.csv]
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2021-07-05 Add files via upload
    agregue datos del fluke prueba fin de semana
    [fluke_01-07-2021_05-07-2021.csv]
2021-07-06 hermetica800ppm y ambiente caja
    [ambiente_001_2021-07-02_2021-07-05.csv, cajahermetica800ppm.csv, sensores_01-07-2021_al_05-07-2021.csv]
2021-07-06 agregue datos fluke prueba ventilador
    [fluke_ventilador_01.csv, fluke_ventilador_02.csv, fluke_ventilador_03.csv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]
2021-07-07 caja hermetica con ventilador
    [sensores_05-07-2021_al_07-07-2021.csv]
2021-07-07 Arduino UniversalShield and universal code
    Adding Arduino Universal Shield and Universal Code (more o less)
    Requires Arduino Uno WiFi Rev. 2 for Serial1
    PIN usage:
    * For UART sensors:
    0 RX
    1 TX
    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
    [UniversalShield.fzz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]
2021-07-07 Universal Shield v1.1
    Damn! SEN0220 connects RX with RX and TX with TX, instead of common
    sense UART connections RX-TX / TX-RX.
    SEN0220 is used as reference sensor, so changed to match SEN0220
    connector.
    Other UART sensor must follow RX-TX / TX-RX convention.
    [UniversalShield_copperBottom.gbl, UniversalShield_copperTop.gtl, UniversalShield_maskBottom.gbs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]
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2021-07-07 Added POST_INTERVAL_MS
    Defines the post interval in milliseconds to MQTT broker.
    Default: one read/post every 60 seconds.
2021-07-08 Fixed mistaken CREDENTIALS in arduino_secrets.h
    Vaya, por fin regresó el iZZi. Corrigiendo las CREDENCIALES
    de acceso al thingsboard.
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2021-07-20 añadi datos del fluke prueba de hoy 20/07/2021
    [fluke_20-07-2021_prueba.csv]
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2021-07-23 agruegue datos Fluke de la prueba 700 y 800 ppm
    [fluke_23-07-2021_prueba700_800.csv]
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2021-07-26 agregue nuevamente pruebas del dia 23/07/2021
    [fluke_23-07-2021_prueba700.csv, fluke_23-07-2021_prueba800.csv]
2021-07-26 agregue datos del fluke (4 pruebas de hoy 26/07)
    [fluke_26-07-2021_pruebas.csv]
2021-07-27 co2 520, 625, 750, 800 ppm
    [fluke_26-07-2021_520ppm.csv, fluke_26-07-2021_625ppm.csv, fluke_26-07-2021_750ppm.csv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]
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2021-07-30 agregue datos del fluke y disp nuevos prueba 800
    [Disp_nuevos_prueba800.csv, Disp_nuevos_prueba800.xlsx, fluje_30-07-2021_prueba800.csv]
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2021-08-05 Default sensor is S8LP
    Now default sensor is S8LP instead of DUMMY
    Fixed typos.
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2021-08-05 Fixed list of sensors
    Just fixed list of sensors to include:
    * DUMMY
    * SEN0219
    * MH-Z14A
    * T3022
    * S8LP
    * SCD30
    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
2021-08-09 s/ArduinoHttpClient/ESP8266HTTPClient/
    Se cambió la biblioteca ArduinoHttpClient por ESP8266HTTPClient
    Aunque ya no revienta, sigue sin postear, error=-1:connection
    failed
    ¿Será que no le gusta postear dentro del ticker?
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2021-08-10 agregue scr s8lp con codigo de rgb y buzzer
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2021-08-10 agregue pin layout de sensores con el esp8266
    [PIN LAYOUT.xlsx]
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2021-08-10 monitorCO2 pin reference 2021-08-10-000
    Primera revisión del monitorCO2 con la referencia de pines del
    2021-08-10-001
    Creo que hay un conflicto con LED_BUILTIN y BUZZER
    En todo este tiempo LED_BUILTIN parpadea rápidamente si hay algún
    problema, y lentamente en operación normal.
    [monitorCO2.ino]
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2021-08-10 Prueba del Buzzer con la biblioteca Ticker
    Para no bloquear el monitorCO2 con delays
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2021-08-10 Se ha eliminado el uso del LED_BUILTIN como testigo de operación
    En algunos lugares he agregado mostrar los códigos de error en el
    display
    [monitorCO2.ino]
2021-08-11 Fixed chkwifi() report on display
    Faster report chkwifi() on display
    [monitorCO2.ino]
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2021-08-12 agregue esquematico y vista proto de ESP8266_CO2
    [ESP8266_C02.fzz]
2021-08-12 agregue correción del esquematico
    [ESP8266_C02.fzz]
2021-08-12 agregue correcion de esquematico CO2
    [ESP8266_C02.fzz]
2021-08-12 added function viod powerOnSelfTest(void)
    Una breve rutina de auto prueba al encender.
    Se encienden todos los segmentos del display (8888)
    Se prueban cada unos de los LED en orden: RED GREEN BLUE}
    Se prueba el BUZZER con tres pitidos cortos
    Se prueba el BOTON_0: si se mantiene presionado se repite la POST
    [monitorCO2.ino]
2021-08-13 hize una pequeña correcion en el esquematico
    [CO2_ESQUEMATIC.fzz]
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2021-08-13 agregue correcion de esquematico
    [CO2_ESQUEMATIC.fzz]
2021-08-18 agregue archivos gerber y fritzing del pcb
    [ESP82_CO2.fzz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]
2021-08-18 corregi las perforaciones pcb ya actualize gerber
    [ESP82_CO2.fzz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]
2021-08-21 Prueba de concepto WIFI-AP -> WIFI-STA
    Si el EEPROM está vacío arranca como ACCESS_POINT con SSID=monitorCO2-MAC-ADDRESS
    Si el EEPROM tiene datos los utiliza para conectarse a la red indicada
    Se configura un WebServer con tres URI iniciales:
    / RootPage: debe presentar un formulario pidiendo los datos y apuntando a /commit
    /commit recibe el formulario, copia los datos y escribe la EEPROM
    /clear sirve para borrar la EEPROM mientras hacemos pruebas
    Por el momento hay que darle RESET al ESP8266 -- pero el diseño actual no tiene botón de reset!
    [myEEPROM.cpp]
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2021-08-21 BASIC HTML POST FORM / COMMIT
    Simple página Web con un formulario POST y una entrada de datos: ACCESS_TOKEN
    Simple página web para el commit que graba los datos a la EEPROM
    Sigue el URI /reset para borrar la EEPROM mientras se hacen las pruebas
    Ya se puede copiar al programa principal, pero ya tengo sueño
2021-08-23 agregue gerber con medidas correctas del esp lolin
    [ESP82_CO2.fzz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]
2021-08-25 agregue gerber con espacio correcto para ESP v3
    [ESP82_CO2.fzz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]
2021-08-26 quite perforaciones de display anterior de pcb
    [ESP82_CO2.fzz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]
2021-08-26 quite perforaciones de display de pcb
    [ESP82_CO2_contour.gm1, ESP82_CO2_copperBottom.gbl, ESP82_CO2_copperTop.gtl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]
2021-08-30 reacomode las perforaciones de las esquinas
    [ESP82_CO2.fzz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]
2021-08-31 gire posicion de buzzer por motivos de la carcasa
    [ESP82_CO2.fzz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]
2021-08-31 agregue las 6 caras de la carcasa en STL
    [cara_atras.stl, cara_costado_derecho.stl, cara_costado_izquierdo.stl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]
2021-09-01 pcb revisado y listo para produccion
    [ESP82_CO2.fzz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]
2021-09-02 POST/EEPROM/WiFi/AP/STA behavior
    Promoted sandbox/test-wifi-ap operations to main program:
    1) Empty EEPROM puts monitorCO2 into AccessPoint mode
    join to network and point to http://192.168.4.1/
    to fill in the blanks
    2) Submit form and after response reset monitorCO2
    3) Now monitorCO2 reads data from EEPROM and starts station mode
    as usual
    4) During POST (Power On Self Test) keep pressed BUTTON_0 at
    least three times, release it, and EEPROM will be ERASED!
    [monitorCO2.ino, myEEPROM.cpp]
2021-09-04 Added reset on MAX_READ_ERRORS. Commented CMA.
    CMA is commented.
    Added reset on MAX_READ_ERRORS
    [monitorCO2.ino]
2021-09-04 Fixed typos
    Fixed typos
    [monitorCO2.ino]
2021-09-10 agregue datos de prueba de 420 7 600 ppm
    [geotermia_400ppm.csv, geotermia_600ppm.csv, sensores_prueba_08-09-2021.csv]
2021-09-13 agregue datos fluke pruebas 13/09/2021
    [fluke_13-09-2021_prueba500.csv, fluke_13-09-2021_prueba600.csv, fluke_13-09-2021_prueba700.csv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]
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2021-09-14 agregue datos de TB de pruebas del dia 13/09/2021
    [sensores_prueba_13-09-2021.csv]
2021-09-20 Reset after MAX_WIFI_ERRORS=8
    Also added CO2_MIN=400, CO2_MID=600 and CO2_MAX=800
    [monitorCO2.ino]
2021-09-20 Fixed misplaced static readErrors
    12e7c3b194e58aec6e767c8ab71174a5
    [monitorCO2.ino]
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2021-09-23 agregue datos del fluke de pruebas de hoy 23/09
    [fluke_23-09-2021_prueba_conVinagre.csv, fluke_23-09-2021_prueba_sinVinagre.csv]
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2021-09-24 agregue datos fluke prueba noche del 23-24 Sept
    [Fluke_24-09-2021_prueba_NocheCompleta.csv]
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2021-09-28 agregue archivos stl y editables de carcasa CO2
    [cara_frontal.stl, cara_trasera.stl, caseCO2_frontal.FCStd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]
2021-09-28 agregue archivos gerber y editable del PCB
    [PCB_CO2.fzz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]
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2021-09-29 agregue datos fluke de la prueba de 900 ppm 28/sep
    [fluke_28-09-2021_prueba900.csv]
2021-09-30 agregue datos fluke de la prueba 700ppm del 29/sep
    [fluke_29-09-2021_prueba700.csv]
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2021-10-12 agregue editables de esquematico y PCB en KiCad
    [co2_project.kicad_pcb, co2_project.sch]
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2021-11-16 agregue datos de fluke de la prueba 3-7/Nov/2021
    [fluke_03-11-2021_07-11-2021_caja_abierta.csv]
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2021-11-24 Synced with latest build
    Added missed .h .cpp files
    [myEEPROM.cpp]
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
